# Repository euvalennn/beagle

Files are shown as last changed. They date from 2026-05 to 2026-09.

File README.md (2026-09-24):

# beagle

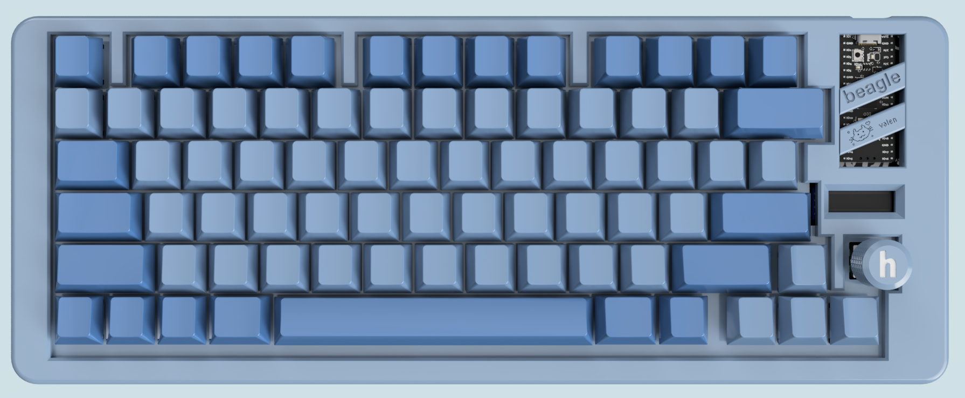
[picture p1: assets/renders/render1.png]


my first (and only) keyboard!!

It's been almost a month since I started working on this! I wanted to try making a keyboard myself, but soon realized it's easier said than done 😭\
Overall I'm really happy with how it turned out, I have to admit it took me a pretty long time to finish but I wanted to make sure it was polished and I think I've achieved that :)

The layout resembles that of my MacBook's keyboard (since that's what I mostly use) and I also included a rotary encoder (intended for volume but can be customized) and an OLED screen to show animations, graphics, or anything else you may want to put there. There's an SK6812MINI-E behind every switch to allow for individual key backlighting.\
I designed the case in Fusion and it consists of an angled base for the keyboard to sit on, the main body of the case covering all of the components from the sides, a plate, and a top part covering it. All of the parts will be put together with 20mm M3 screws, one in every corner.\
The PCB also features a silkscreen hand-drawn by myself! :D

## Features:

- 77 total keys
- rp2040 based mcu
- customizable knob to control whatever your heart desires
- 0.91" OLED screen for graphics and useful info
- neopixels under each switch for RGB backlighting
- sick hand-drawn silkscreen!!

## IRL build pictures

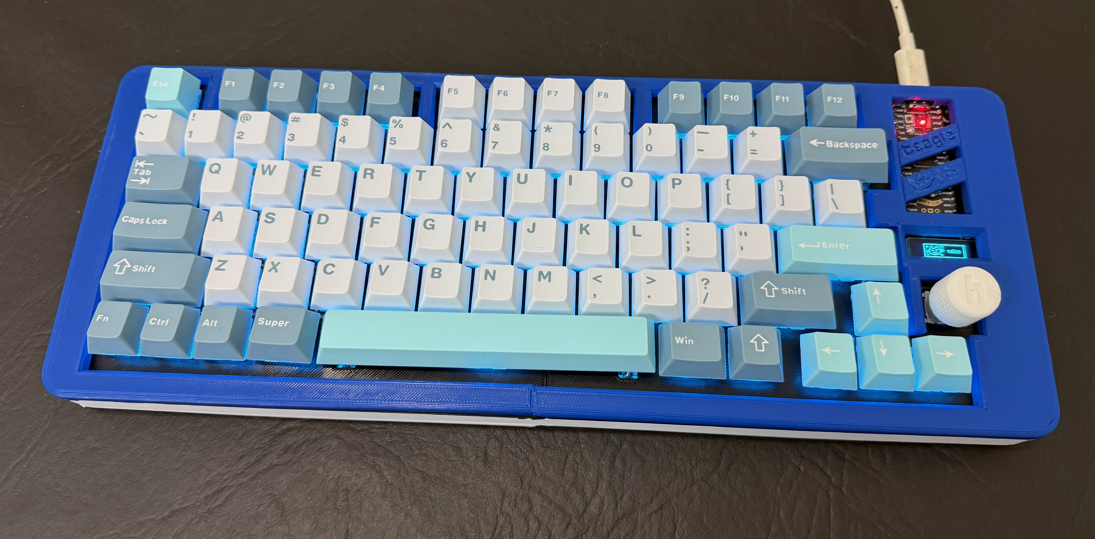
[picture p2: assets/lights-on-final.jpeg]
\
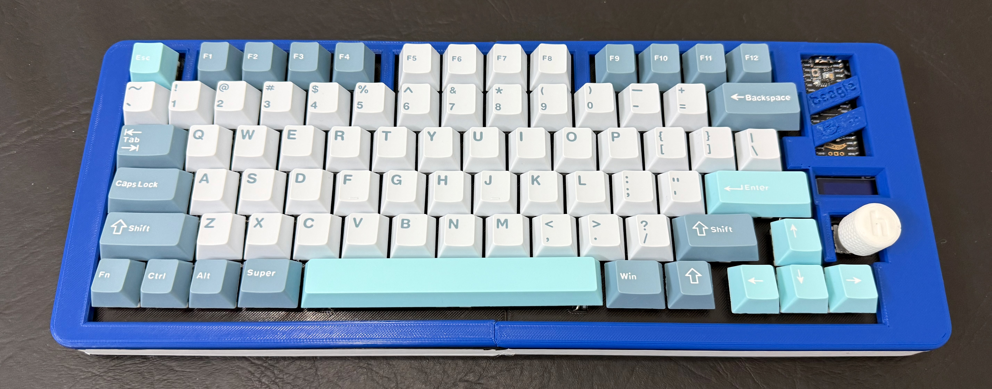
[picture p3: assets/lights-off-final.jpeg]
\
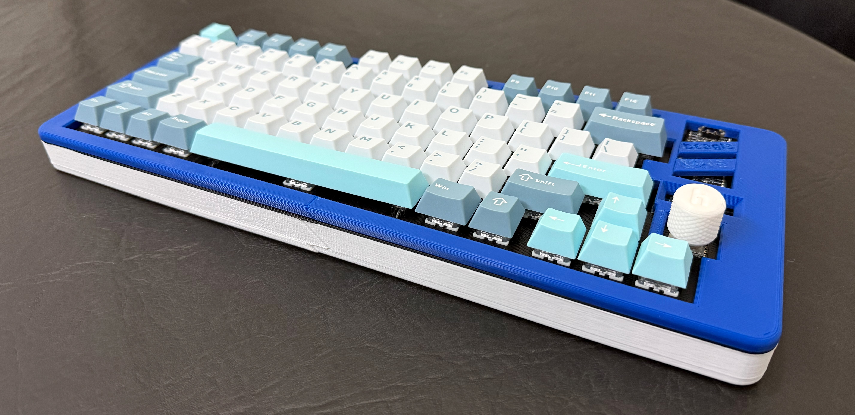
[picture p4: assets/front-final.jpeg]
\
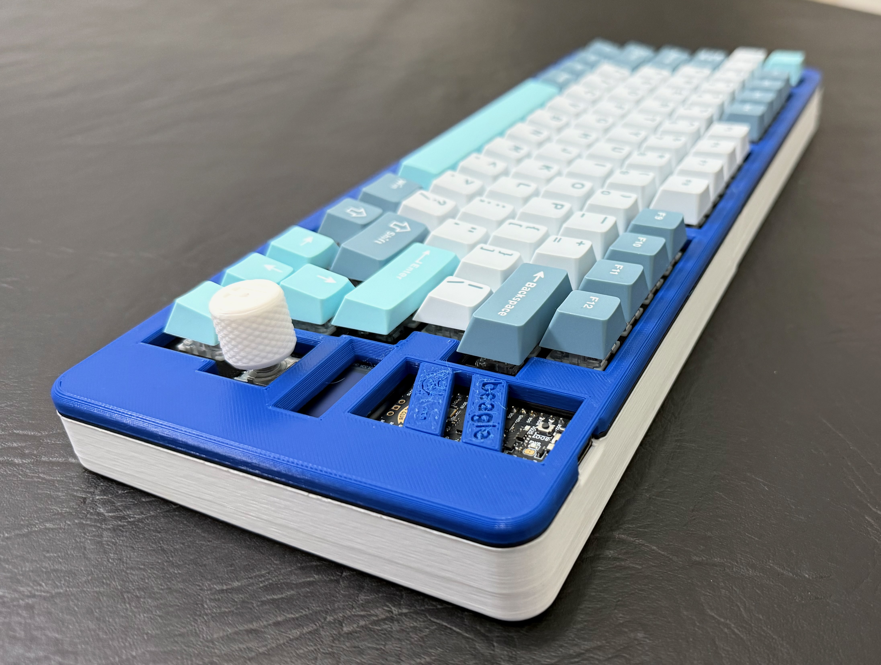
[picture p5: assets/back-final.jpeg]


## More CAD pictures

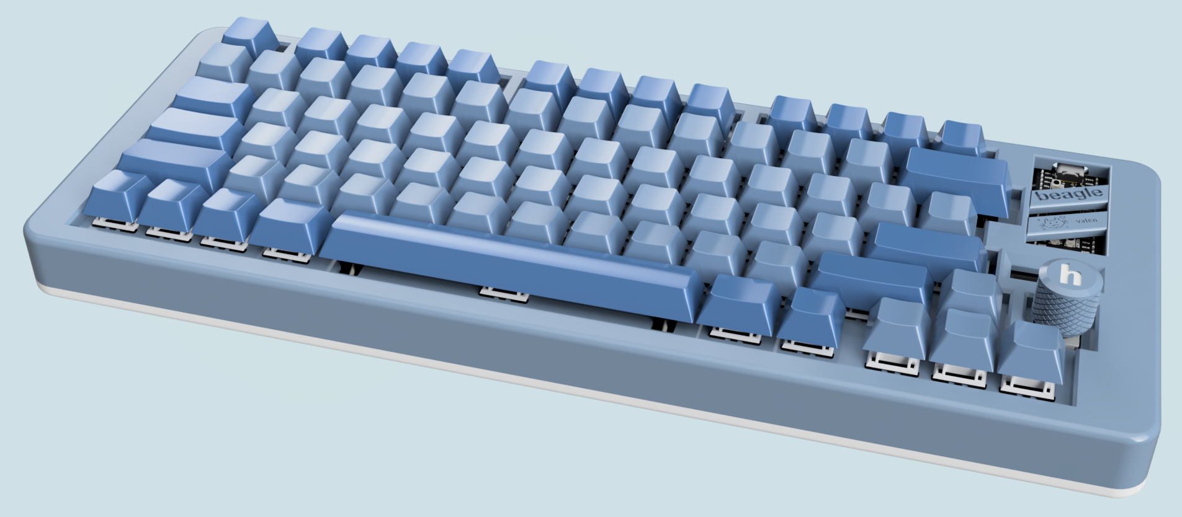
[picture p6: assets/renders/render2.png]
\
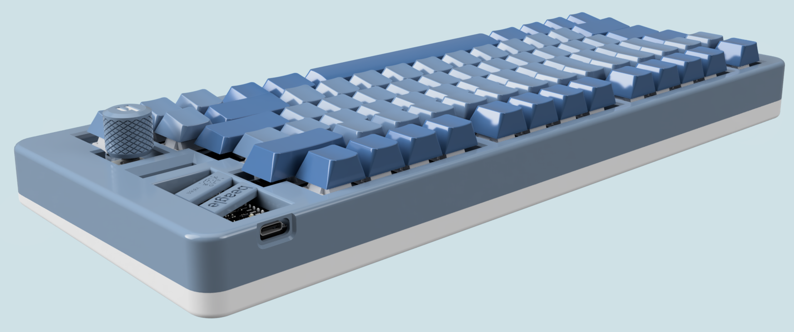
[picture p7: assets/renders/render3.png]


NOTE: the actual color scheme is subject to change based on availability 😭

## PCB and schematics screenshots

see it online [here](https://kicanvas.org/?repo=https%3A%2F%2Fgithub.com%2Feuvalennn%2Fbeagle%2Ftree%2Fmain%2Fpcb)!

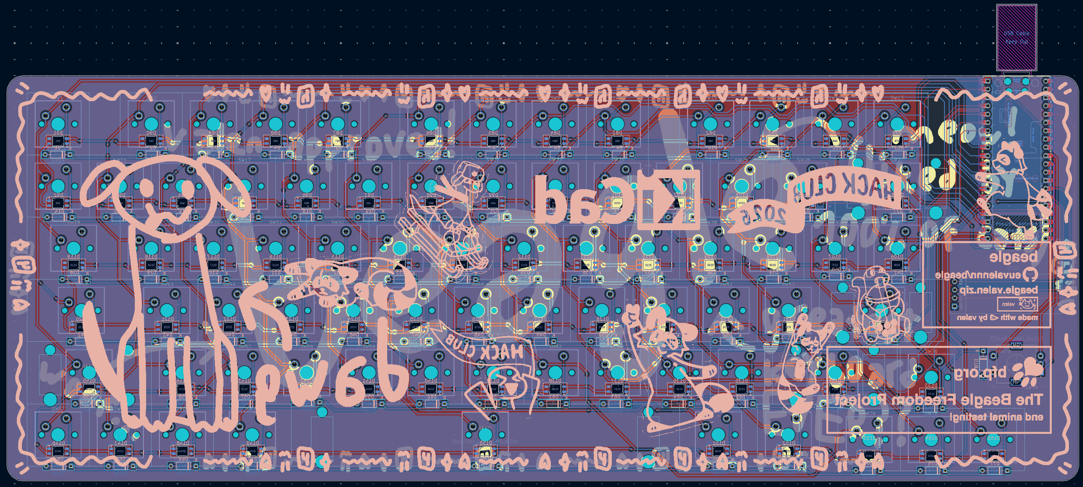
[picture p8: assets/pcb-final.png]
\
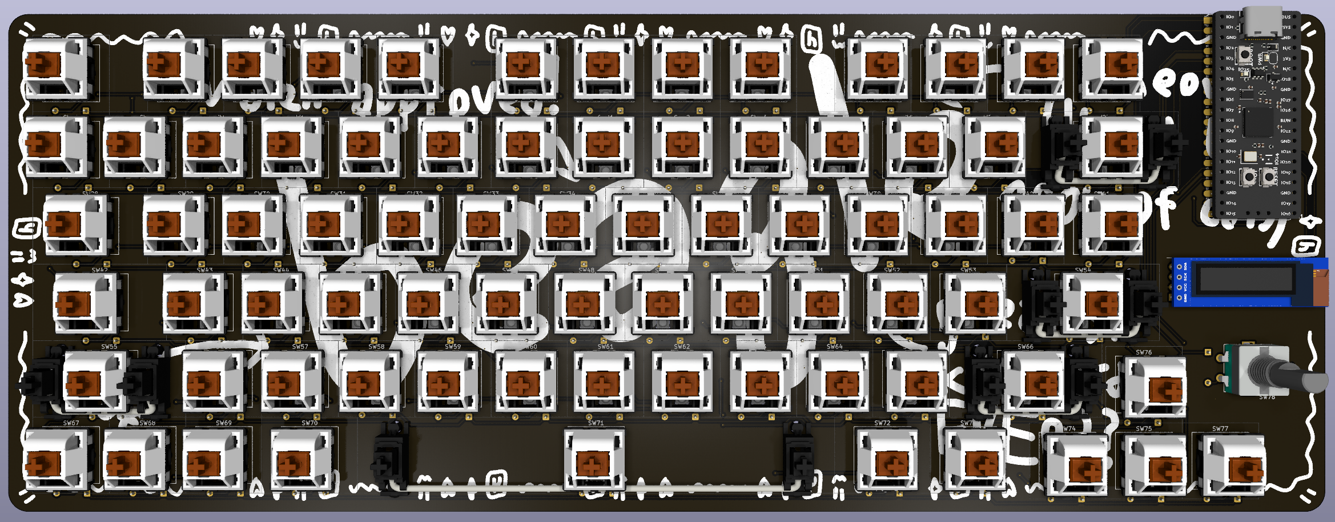
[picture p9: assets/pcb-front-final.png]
\
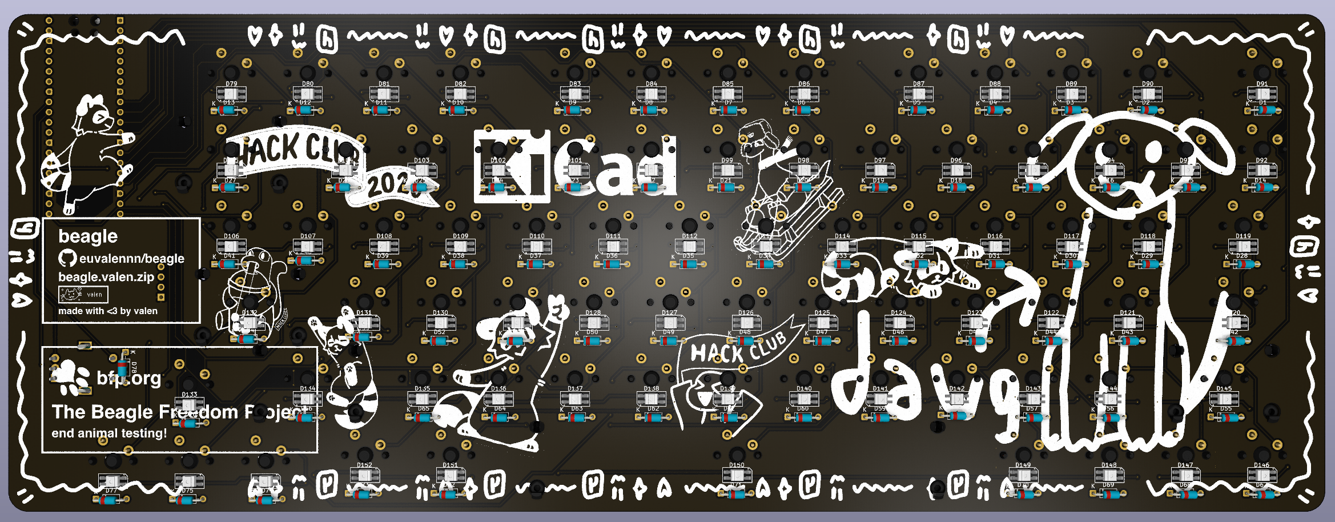
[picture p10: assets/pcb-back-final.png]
\
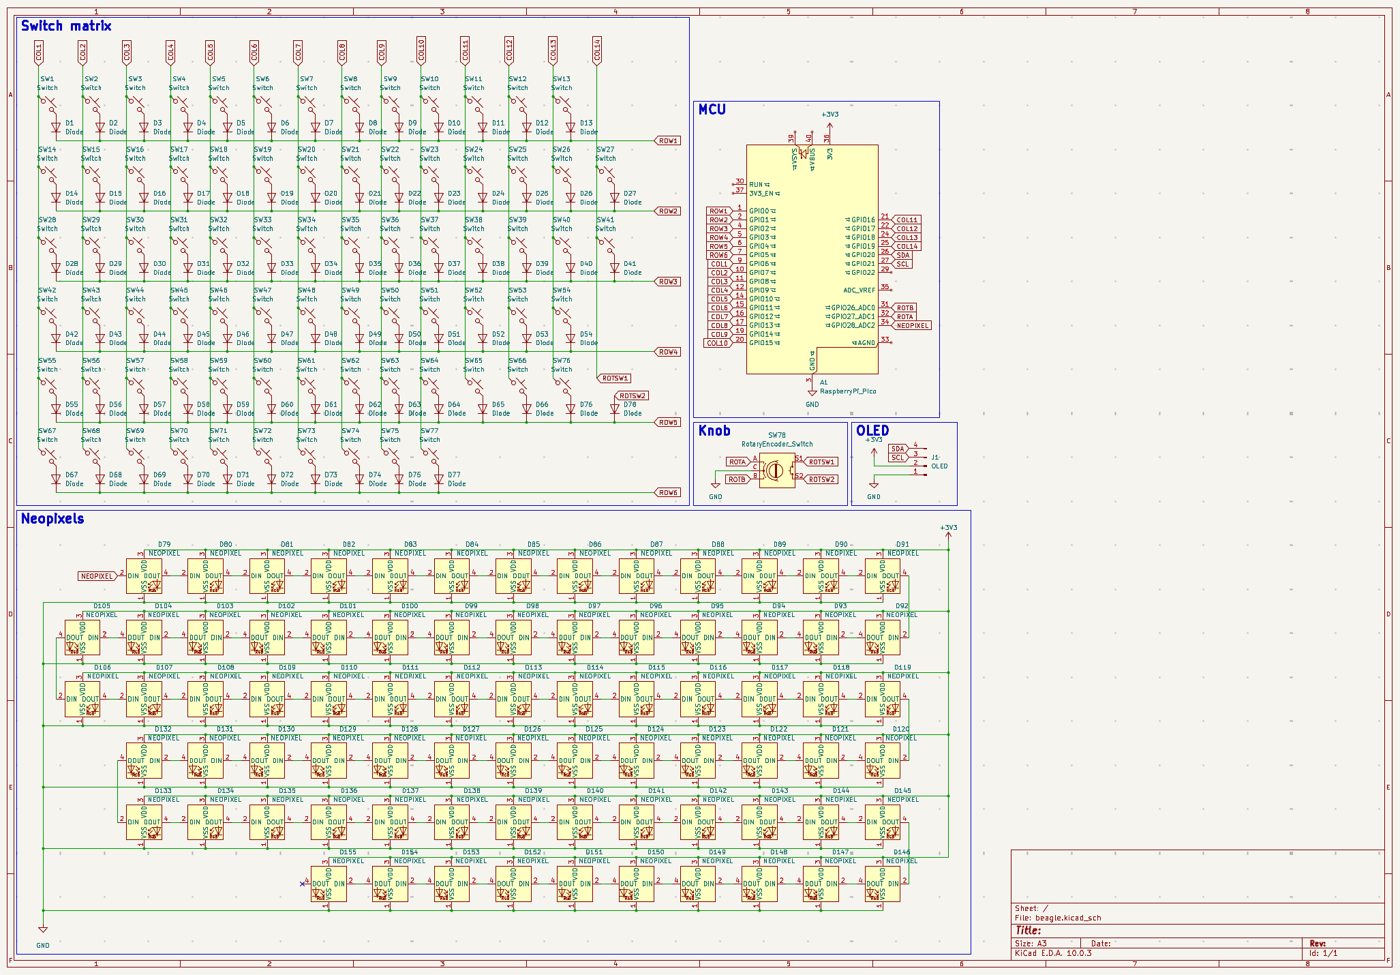
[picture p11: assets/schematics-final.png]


## BOM

| Item | Quantity | Price | Total  | URL |
| --- | --- | --- | --- | --- |
| Orpheus Pico | 1 | Already owned | $0 | N/A |
| OLED display | 1 | $6.06 | $6.06  | https://es.aliexpress.com/item/1005008640108394.html |
| EC11 Rotary encoder | 1 | $5.33 | $5.33  | https://es.aliexpress.com/item/1005007644083514.html |
| SK6812MINI-E | 100 | $10.53 | $10.53 | https://es.aliexpress.com/item/1005005193716172.html |
| 1N4148 diodes | 100 | $5.26 | $5.26  | https://es.aliexpress.com/item/4001126137167.html |
| Keyboard switches | 80 | $1.75 | $1.75  | https://es.aliexpress.com/item/1005012157731141.html |
| M3x5x4 heatset inserts | 30 | $7.04 | $7.04  | https://es.aliexpress.com/item/1005006071488810.html |
| M3 20mm screws | 50 | $8.14 | $8.14  | https://es.aliexpress.com/item/32810872544.html |
| Stabilizers set | 1 | $9.97 | $9.97  | https://es.aliexpress.com/item/1005004229140548.html |
| Keycap set | 1 | $15.51 | $15.51 | https://es.aliexpress.com/item/1005007321700850.html |
| AliExpress VAT | 1 | Included in item prices | $0 | N/A |
| PCB | 1 | $22.20 | $22.40 | https://jlcpcb.com |
| PCB shipping | 1 | $48.19 | $47.36 | https://jlcpcb.com |
| 3D printed case | 1 | Will get someone to print it for me | $0 | N/A |
| 3D printed plate | 1 | Will get someone to print it for me | $0 | N/A |
| | | | | |
| Total cost: | $139.35  | | | |

---

thank you to [hack club](https://hackclub.com) for funding this project :D

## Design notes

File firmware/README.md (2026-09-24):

This QMK firmware sets all of the neopixels to a blue-ish color, makes the rotary encoder control the volume and displays my 88x31 button on the OLED display. The layout is the same as that of a regular US MacBook keyboard, including the globe/fn key in the bottom-left corner to switch keyboard layouts or open the emoji picker on macOS.

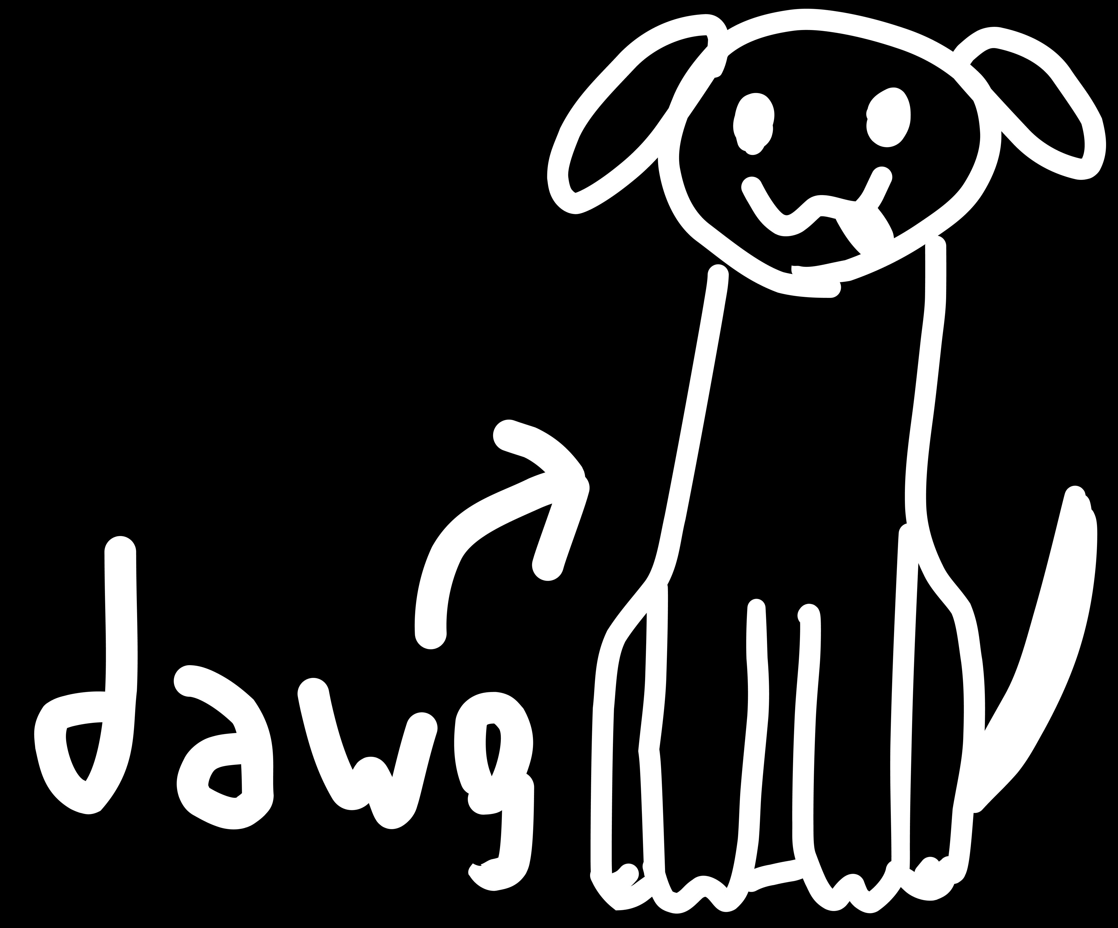
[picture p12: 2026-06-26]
pcb/assets/dawg.png

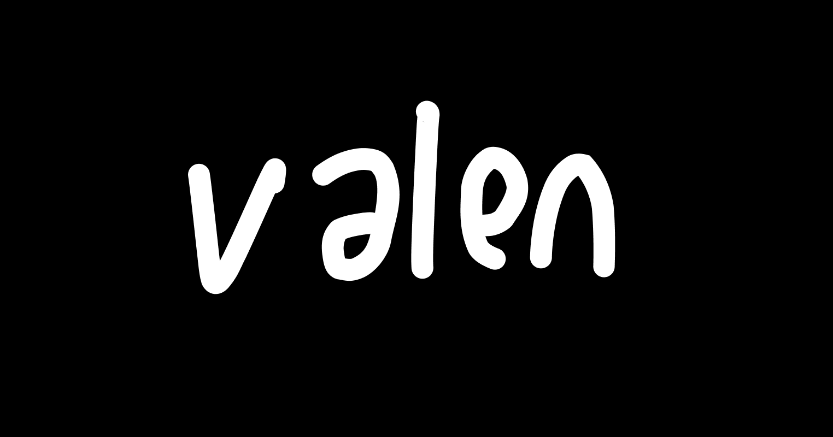
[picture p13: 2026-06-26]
pcb/assets/valen.png

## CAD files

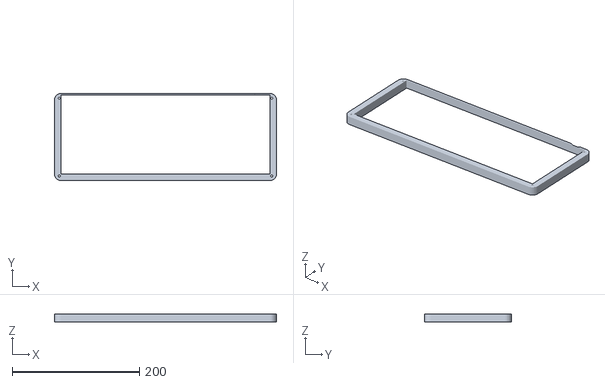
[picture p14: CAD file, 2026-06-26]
production/main-body.stl
349.0 x 137.1 x 13.0

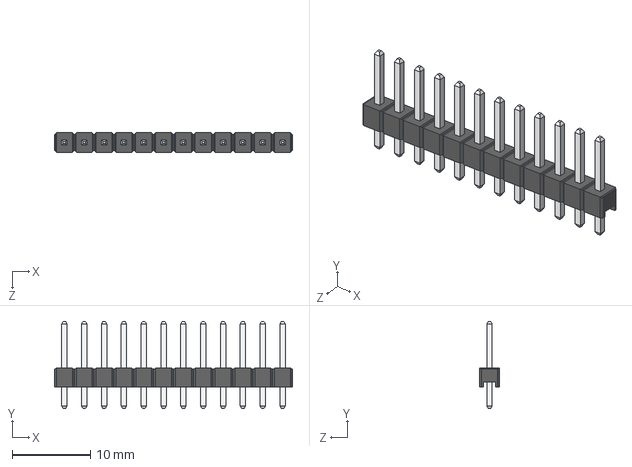
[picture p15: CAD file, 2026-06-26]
pcb/assets/3dmodels/2-54mm-male-pin-header/Step/100mill Male Pin Header_12P_Bk.STEP
30.5 x 11.2 x 2.50 mm

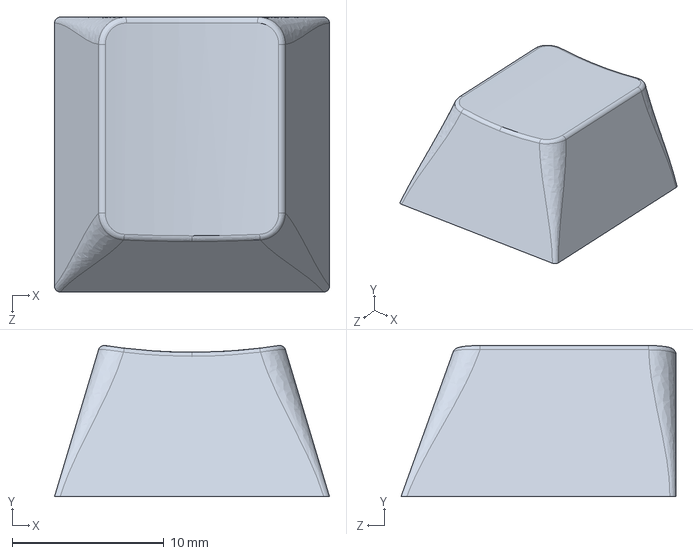
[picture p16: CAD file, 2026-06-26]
pcb/assets/3dmodels/cherry_mx_keycaps/r1/r1_100.STEP
18.1 x 9.95 x 18.1 mm

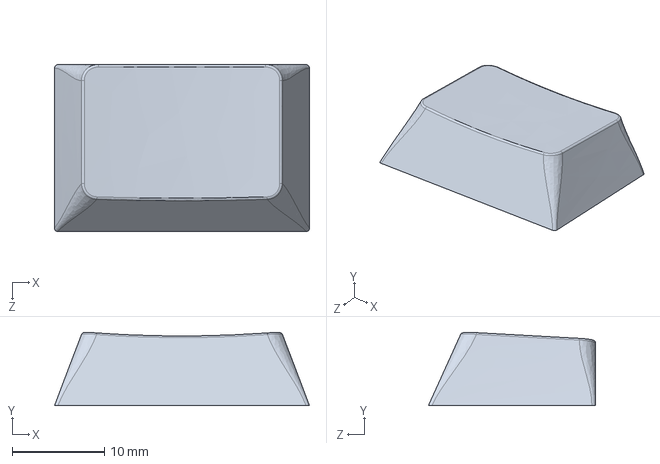
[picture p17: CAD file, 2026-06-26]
pcb/assets/3dmodels/cherry_mx_keycaps/r2/r2_150.STEP
27.6 x 7.92 x 18.1 mm

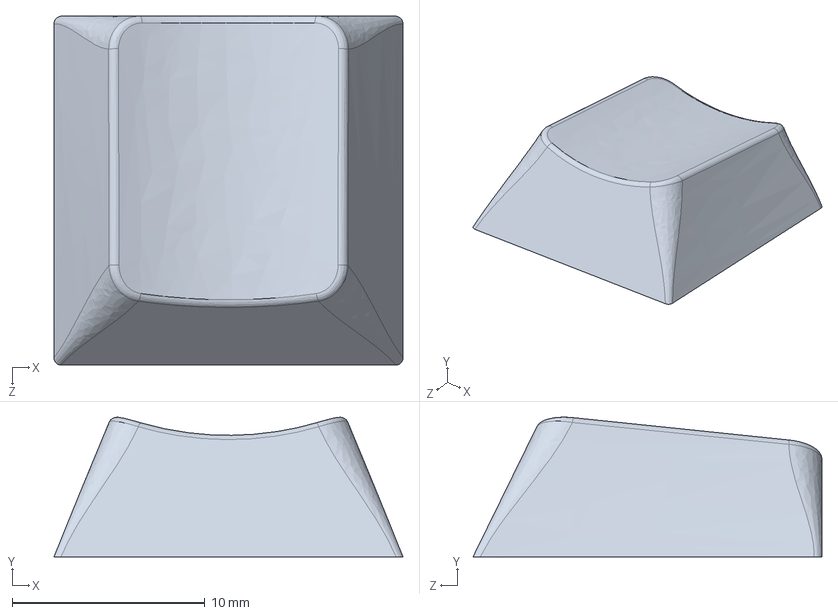
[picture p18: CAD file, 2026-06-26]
pcb/assets/3dmodels/cherry_mx_keycaps/r3/r3_100_sculpted.STEP
18.1 x 7.24 x 18.1 mm

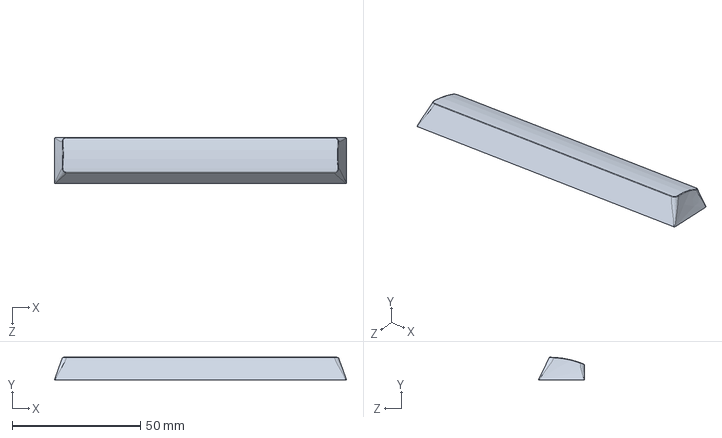
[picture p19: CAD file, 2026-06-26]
pcb/assets/3dmodels/cherry_mx_keycaps/r4/r4_600.STEP
114.0 x 8.80 x 18.0 mm

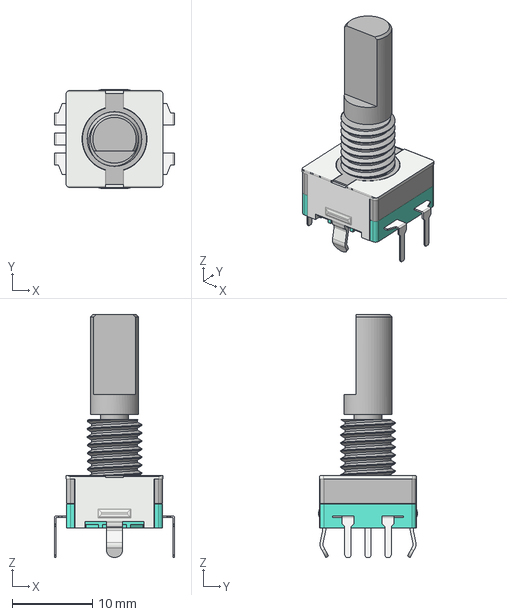
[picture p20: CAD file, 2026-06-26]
pcb/assets/3dmodels/EC11_NEW.STEP
15.0 x 12.3 x 30.3 mm

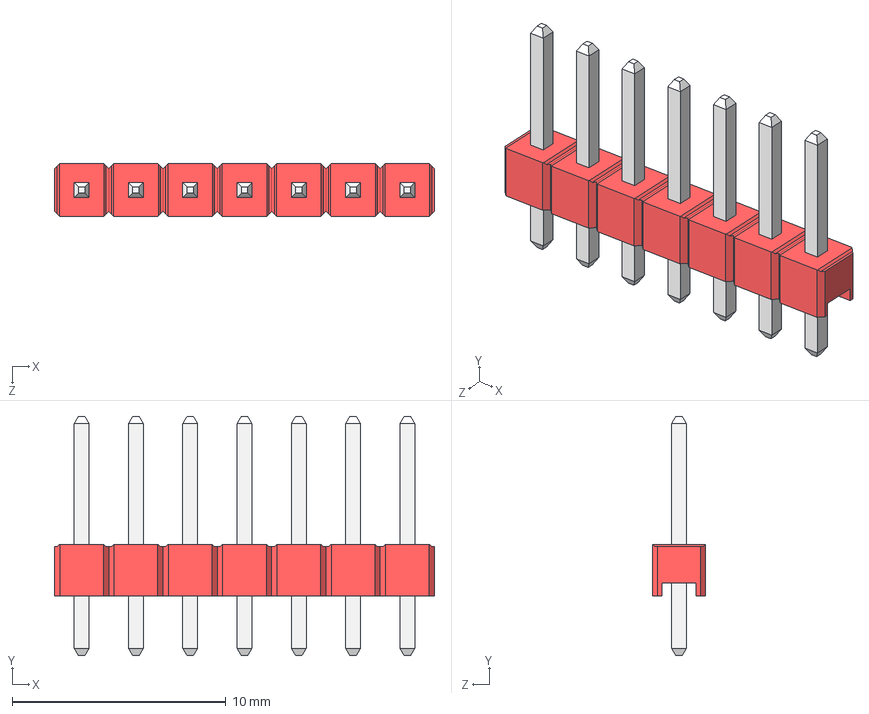
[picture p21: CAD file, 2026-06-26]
pcb/assets/3dmodels/2-54mm-male-pin-header/Step/100mill Male Pin Header_7P_R.STEP
17.8 x 11.2 x 2.50 mm

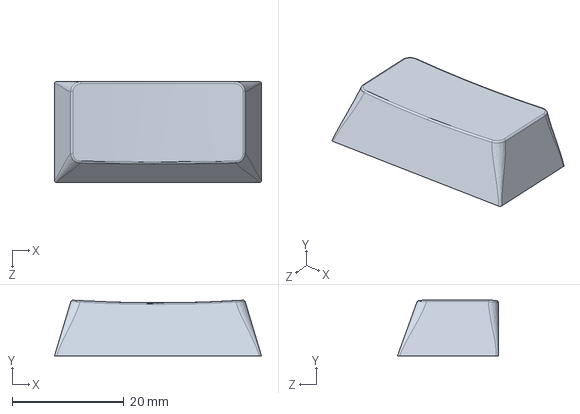
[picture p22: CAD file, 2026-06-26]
pcb/assets/3dmodels/cherry_mx_keycaps/r1/r1_200.STEP
37.1 x 9.98 x 18.1 mm

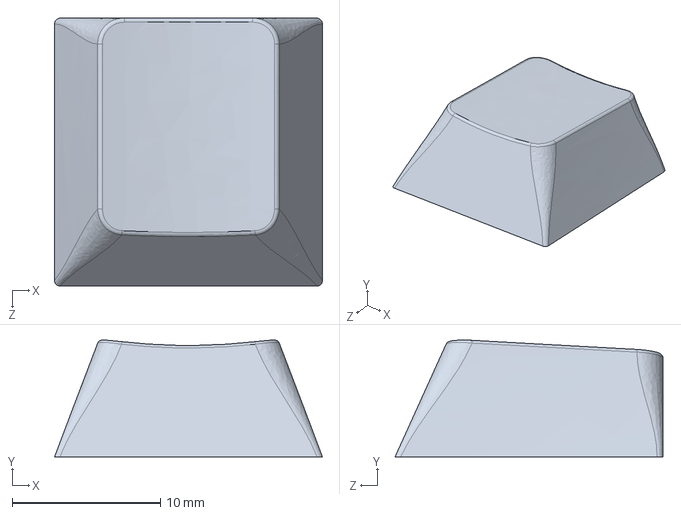
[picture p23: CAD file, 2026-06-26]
pcb/assets/3dmodels/cherry_mx_keycaps/r2/r2_100.STEP
18.1 x 7.89 x 18.1 mm

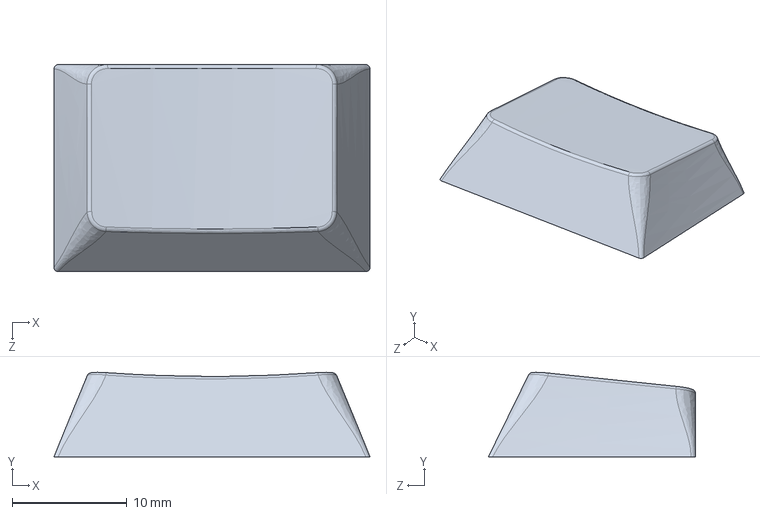
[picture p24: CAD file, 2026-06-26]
pcb/assets/3dmodels/cherry_mx_keycaps/r3/r3_150.STEP
27.6 x 7.38 x 18.1 mm

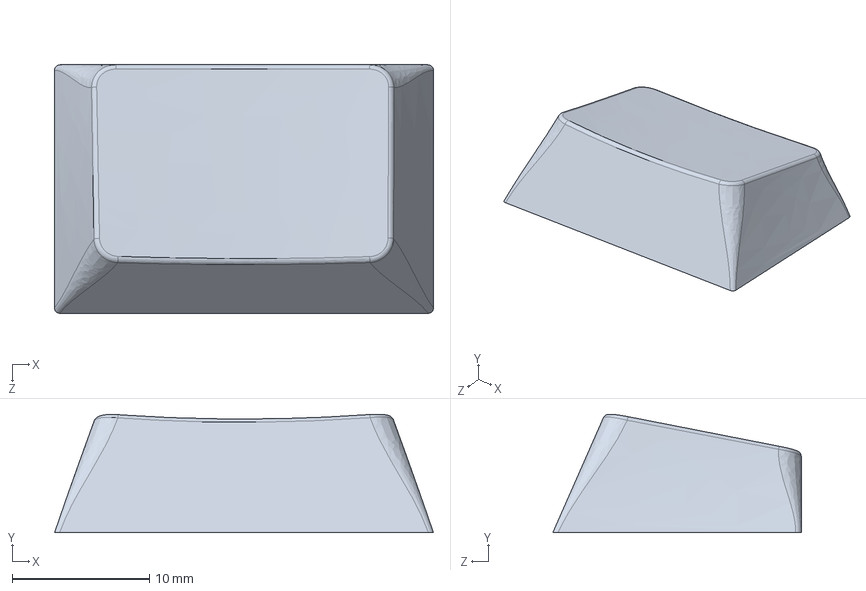
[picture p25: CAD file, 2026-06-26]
pcb/assets/3dmodels/cherry_mx_keycaps/r4/r4_150.STEP
27.6 x 8.63 x 18.1 mm

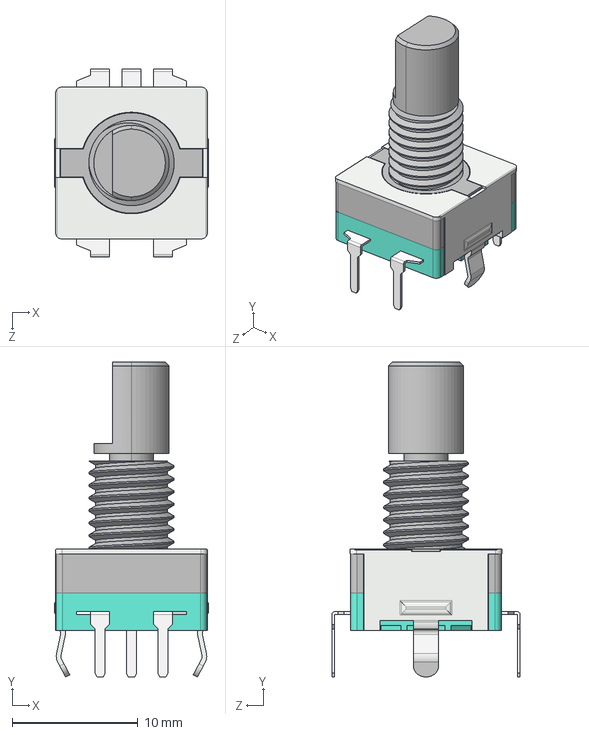
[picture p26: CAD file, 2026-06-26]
pcb/assets/3dmodels/EC11.STEP
12.3 x 25.1 x 15.0 mm

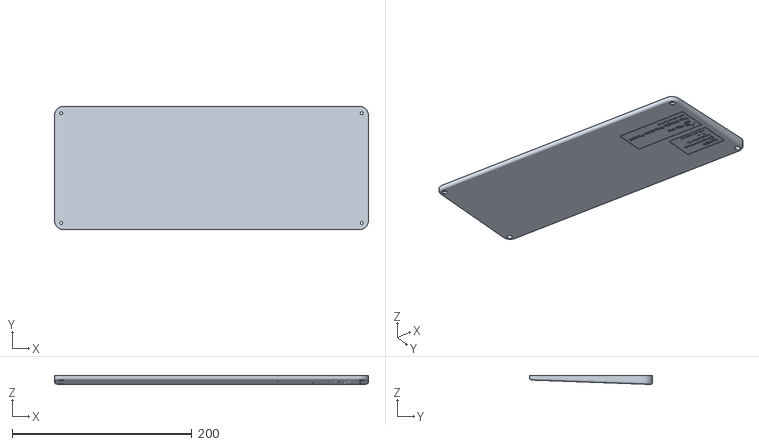
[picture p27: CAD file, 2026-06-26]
production/base.stl
349.0 x 137.0 x 9.91

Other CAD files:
pcb/assets/3dmodels/0.91in OLED Module - Without Glass.stp
pcb/assets/3dmodels/2-54mm-male-pin-header/Step/100mill Male Pin Header_8P_Bk.STEP
pcb/assets/3dmodels/cherry_mx_keycaps/r3/r3_100_bar.STEP
pcb/assets/3dmodels/cherry_mx_keycaps/r4/r3-4_200vert.STEP
pcb/assets/3dmodels/2-54mm-male-pin-header/Step/100mill Male Pin Header_10P_Bk.STEP
pcb/assets/3dmodels/2-54mm-male-pin-header/Step/100mill Male Pin Header_10P_R.STEP
pcb/assets/3dmodels/2-54mm-male-pin-header/Step/100mill Male Pin Header_10P_Y.STEP
pcb/assets/3dmodels/2-54mm-male-pin-header/Step/100mill Male Pin Header_12P_R.STEP
pcb/assets/3dmodels/2-54mm-male-pin-header/Step/100mill Male Pin Header_12P_Y.STEP
pcb/assets/3dmodels/2-54mm-male-pin-header/Step/100mill Male Pin Header_15P_Bk.STEP
pcb/assets/3dmodels/2-54mm-male-pin-header/Step/100mill Male Pin Header_15P_R.STEP
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

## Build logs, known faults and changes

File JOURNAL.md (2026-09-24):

# May 26: Did research, started (and finished!) first schematic design, and positioned all components in the PCB

I wasn't really sure if I could make this because it's been a really long time since I last made a hardware project and making a keyboard sounds a bit complicated but I finally decided to give it a try, so here we are :D

I'm planning on making a 75% keyboard with a 0.91" OLED display, a rotary encoder for volume and an Orpheus Pico as the MCU. It's my first time making a keyboard and I'm not too sure how hard it will be but I've been doing some research and already started designing the PCB.

Here's how the schematic is looking so far:

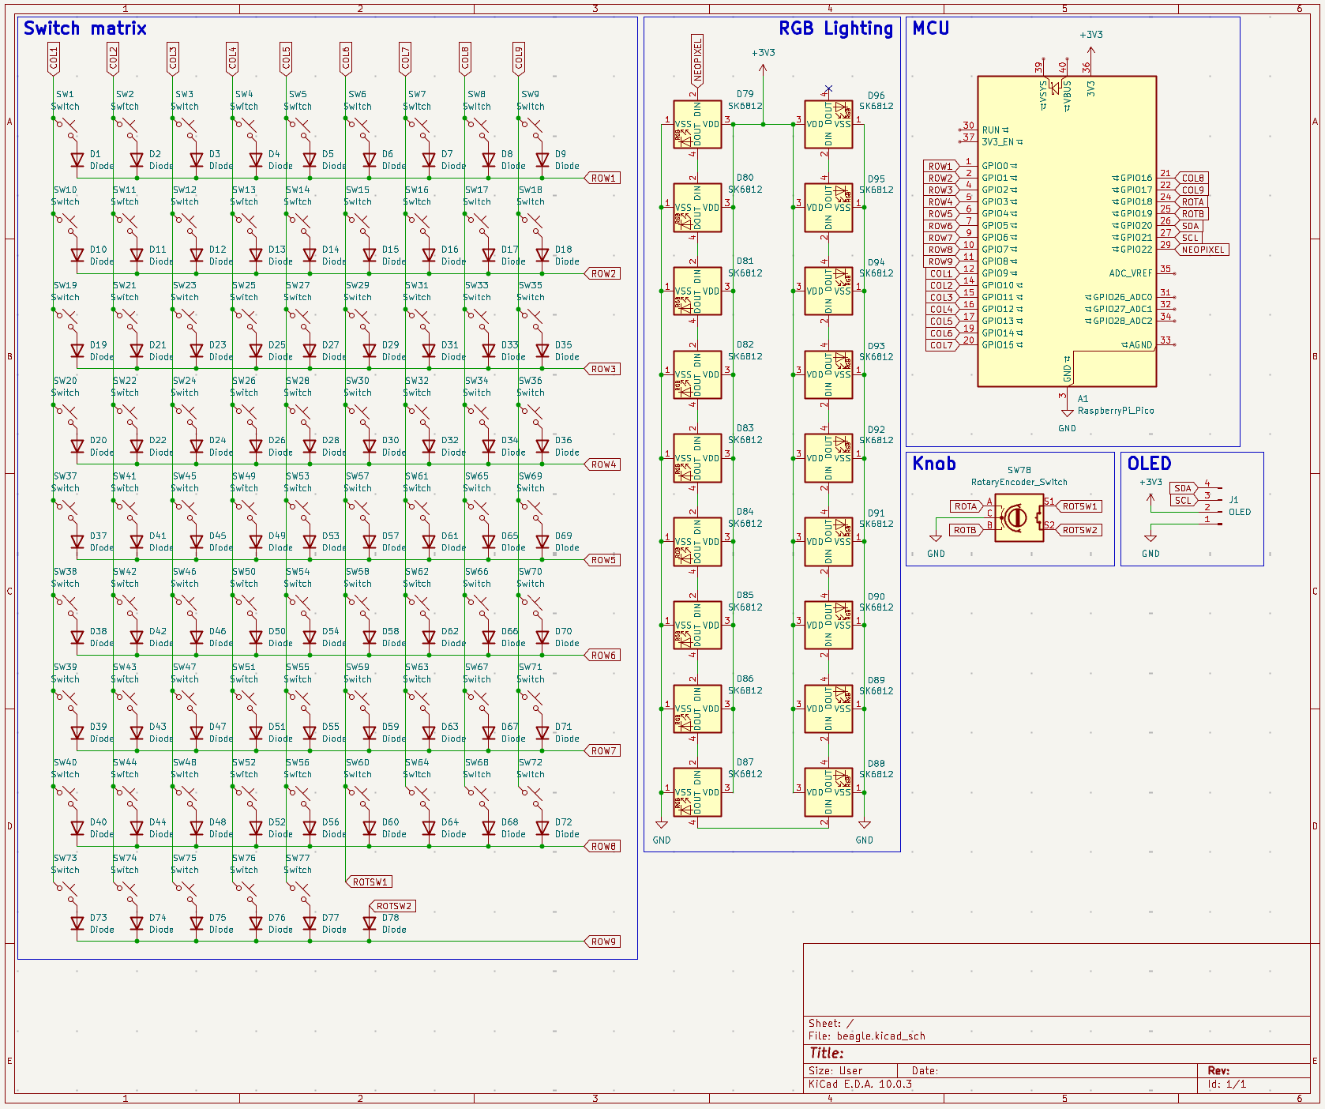
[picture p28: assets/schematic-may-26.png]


I positioned all components in the PCB, although I had to spend some time looking for 3D models and footprints for every one of them (especially the stabilizers) and seeing where to place everything (I'm still not sure if I'll keep the current layout but it serves as a starting point for now, I already spent way too much time on this today so I'll figure it out later 😭)

Here's how the PCB looks right now, both from the editor and 3D viewer:

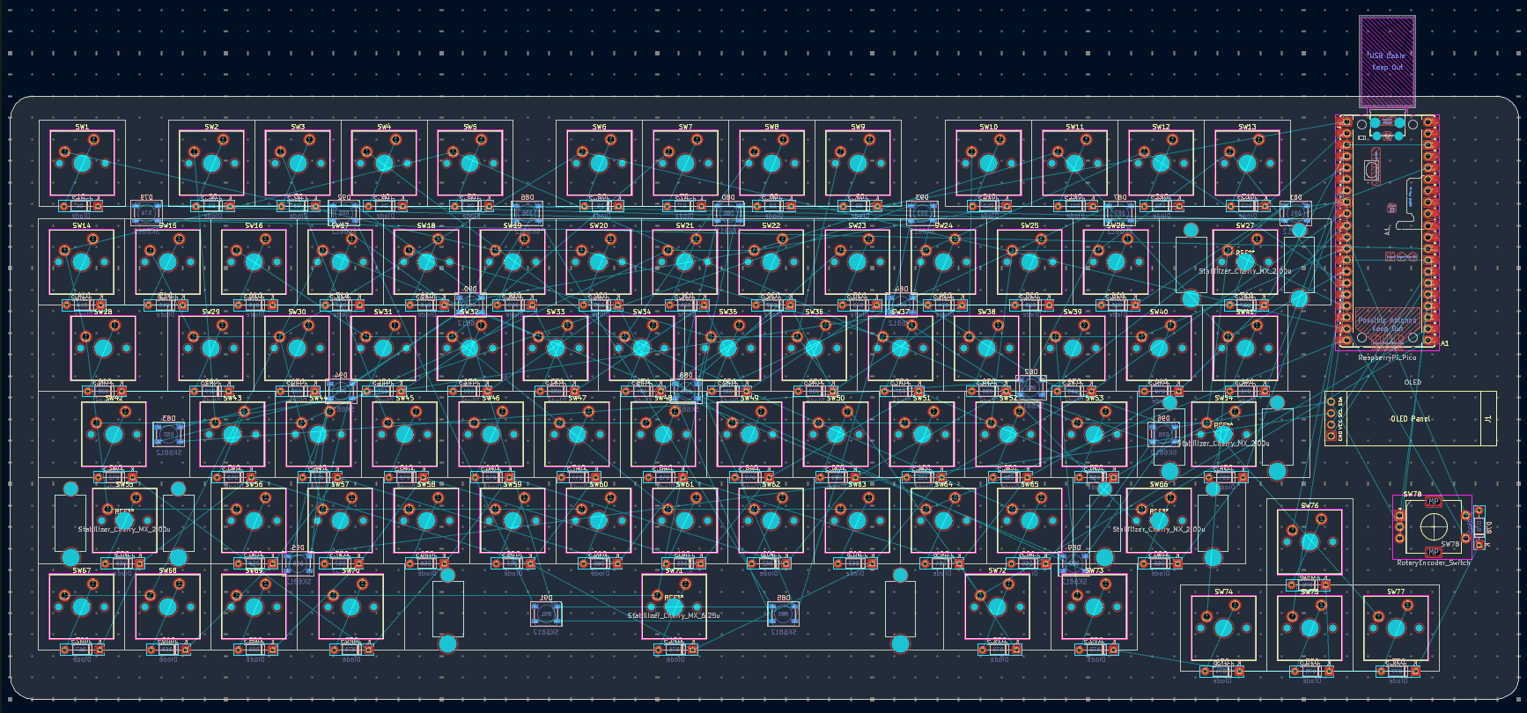
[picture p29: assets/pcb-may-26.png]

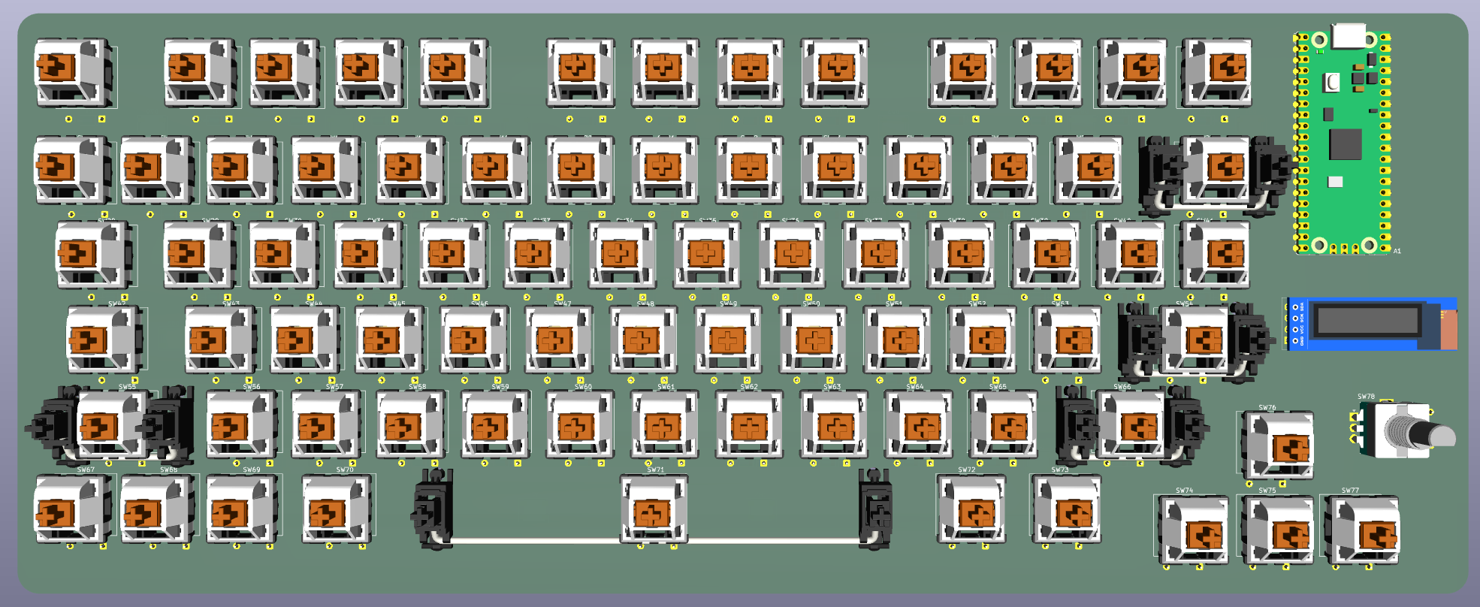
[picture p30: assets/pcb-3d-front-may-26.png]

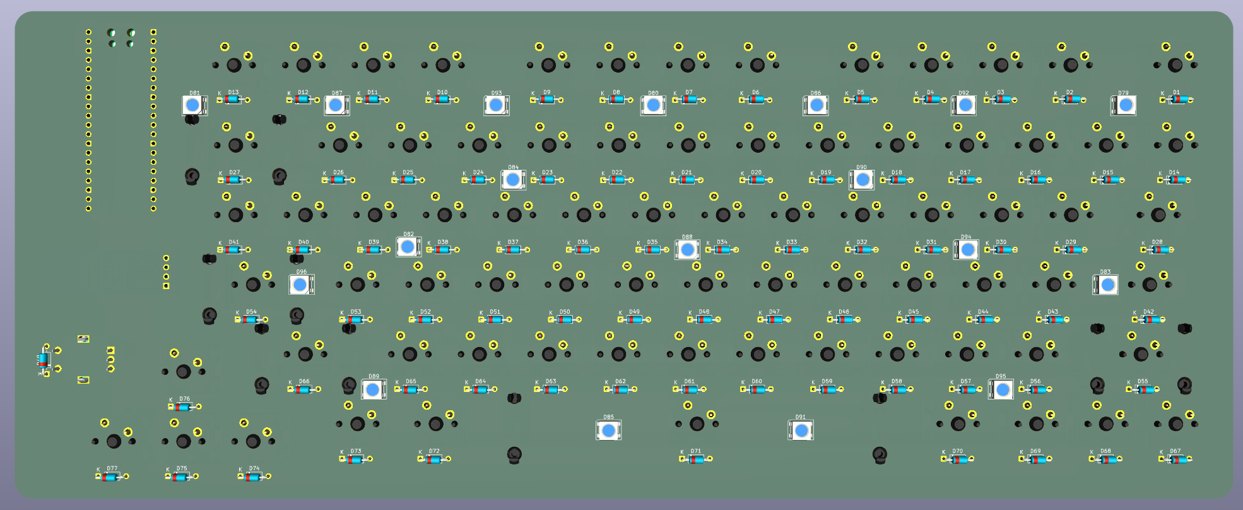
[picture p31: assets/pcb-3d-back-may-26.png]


For the next time I work on this I'd like to figure out the final layout and start routing the PCB!

**Time spent this session: 4h**

# May 28: Updated PCB and switch matrix (schematic) and started routing

I got a lot of stuff done today!!

First off, I moved around some components and switches in the PCB so that the spacing makes more sense and I can make the PCB smaller.

Once I was happy with how the general layout looked, I was going to start routing the switches but then I realized the rows and columns were a total mess :pf:

I had to change the switch matrix in the schematic to reflect how the switches were actually laid out in the PCB and therefore make routing easier.

Here's how the matrix looks now:

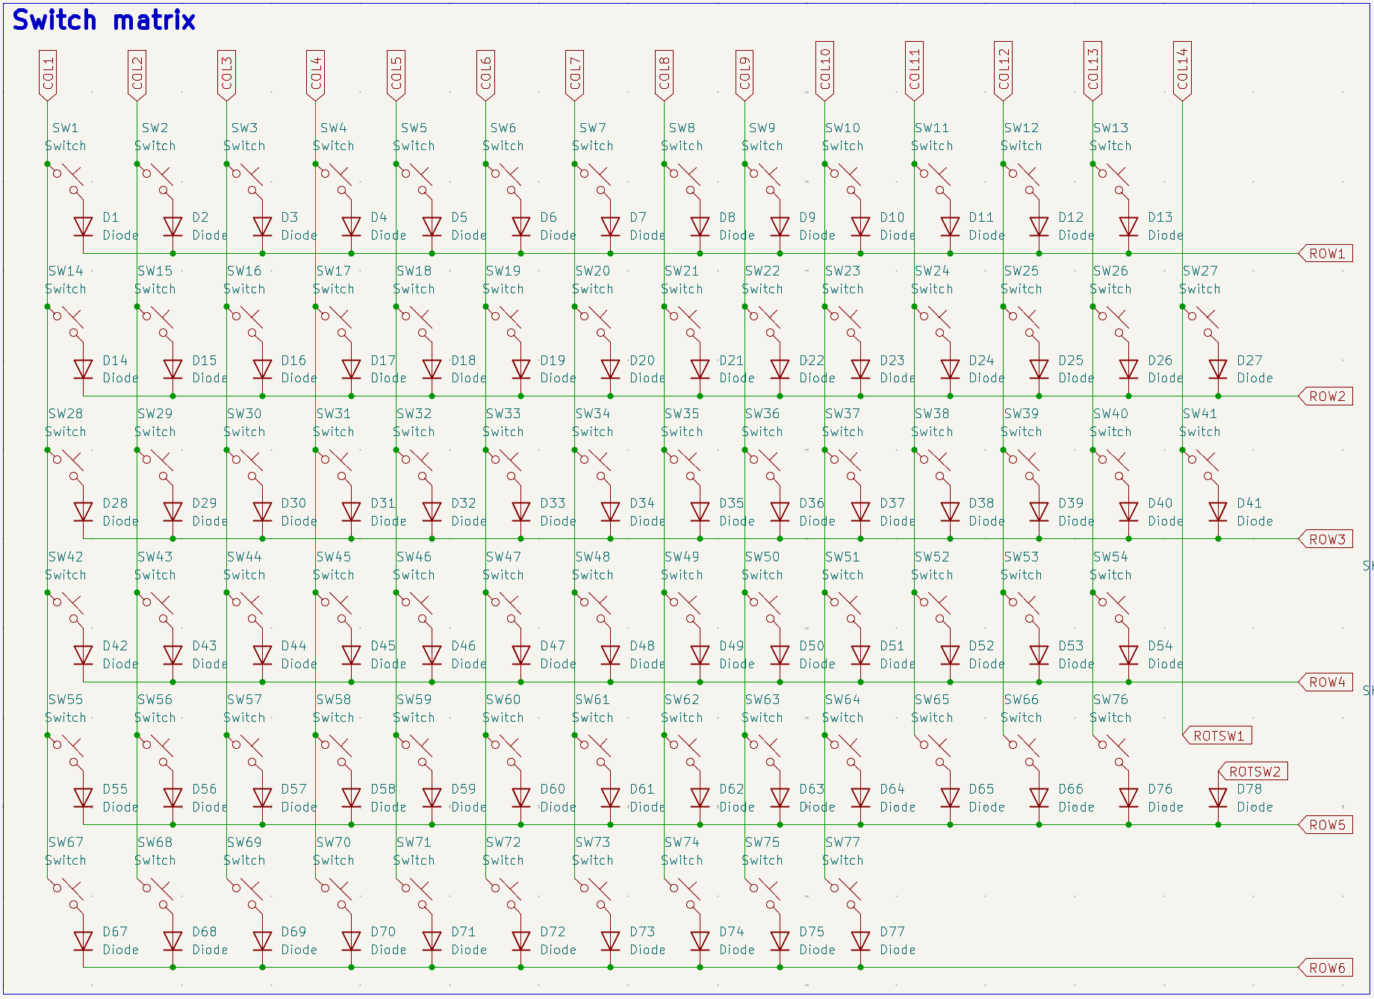
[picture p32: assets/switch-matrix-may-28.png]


Once that was done I started routing everything! I had to redo it a couple of times but here's how the traces look now (I think it looks pretty neat!)

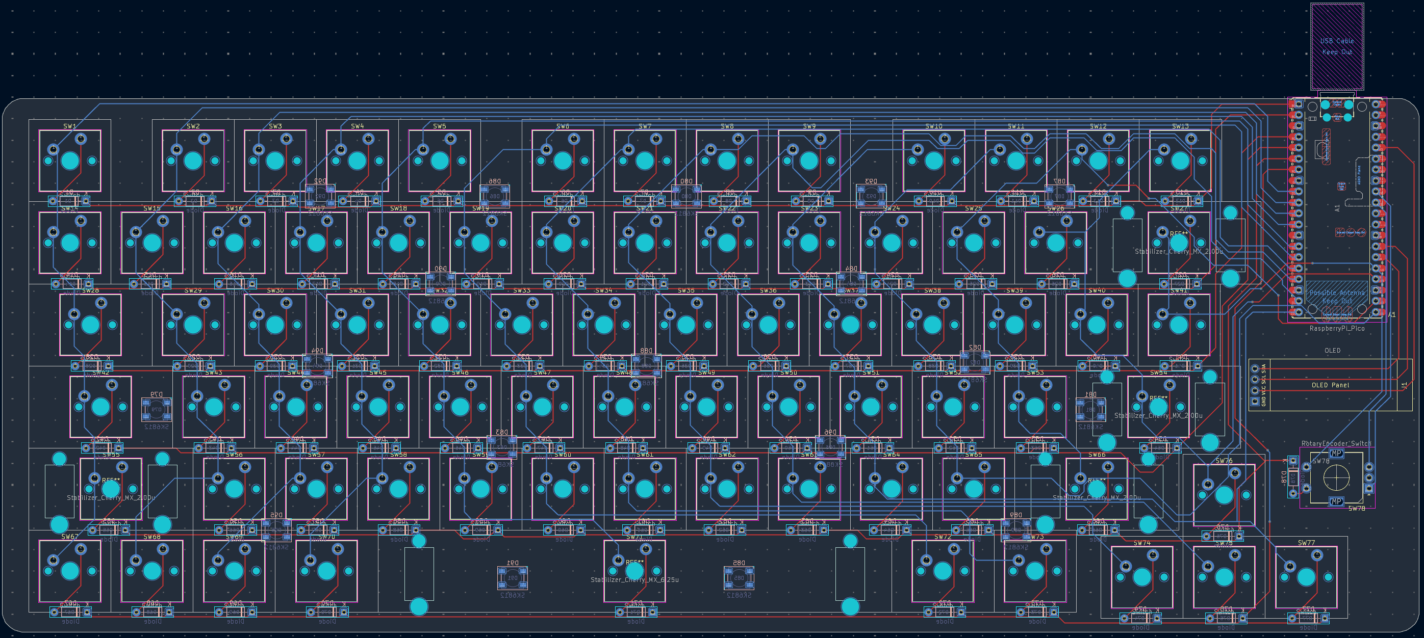
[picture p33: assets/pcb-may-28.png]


Now I only have to route the neopixels (I'll also have to update the schematic for those so that the connections make sense) and add silkscreen art. Once I'm done with that I think I can move on to the case design :D

Here's how the PCB looks right now from the 3D view:

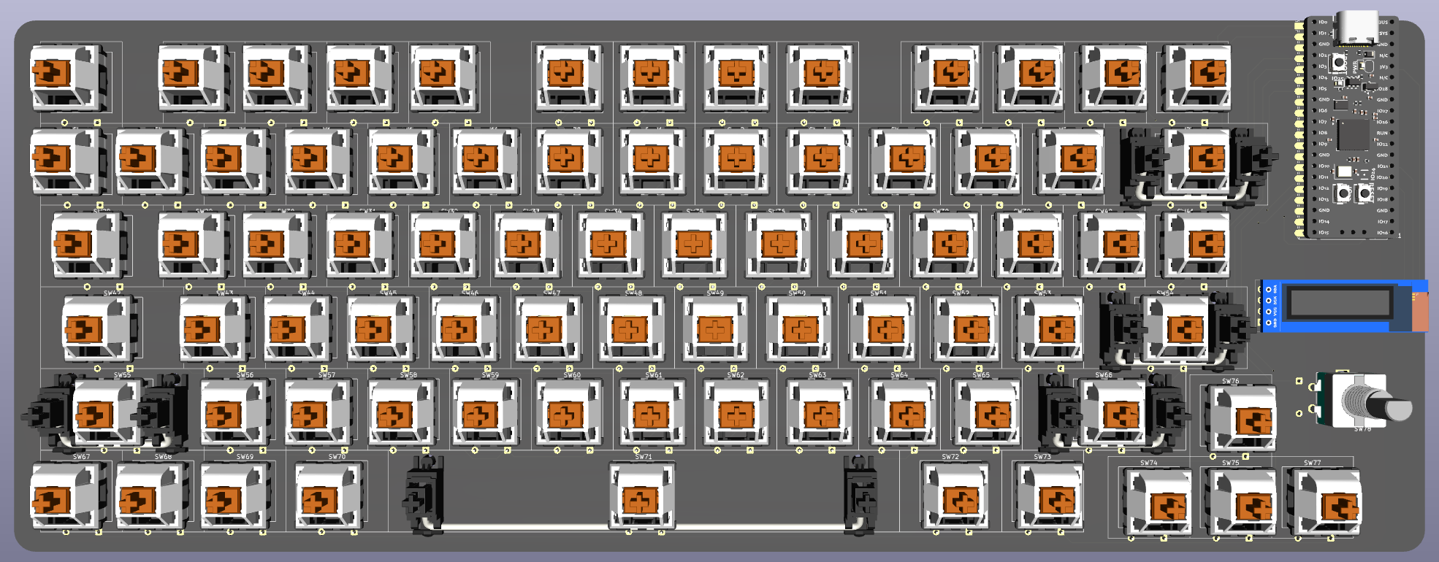
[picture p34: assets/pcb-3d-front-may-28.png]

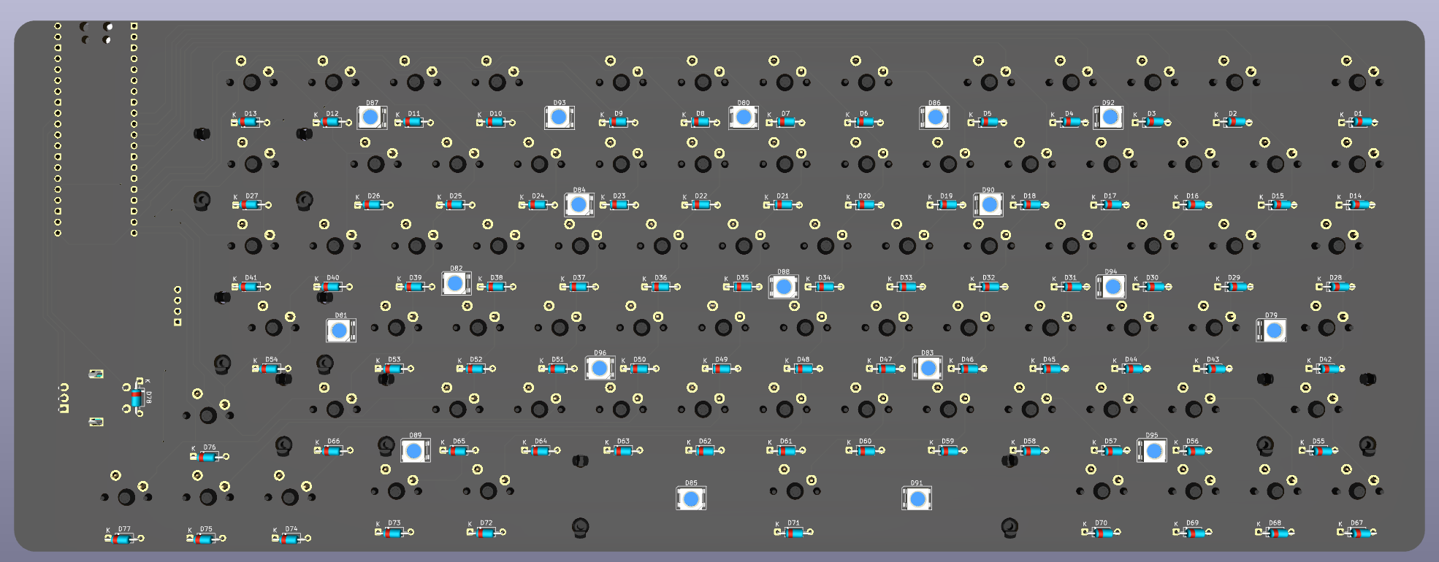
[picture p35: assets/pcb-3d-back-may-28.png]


**Time spent this session: 4h**

# May 30: Did more routing and fixed DRC errors

Today I changed the neopixels' connections on the schematic so that they match the actual layout on the PCB and then started routing! I actually finished routing all of them as well as the VCC connections, so the only thing left to route now is GND. I also ran a DRC check and moved around some components that were overlapping so I shouldn't have any problems with that now.
Here's a pic of the PCB right now:

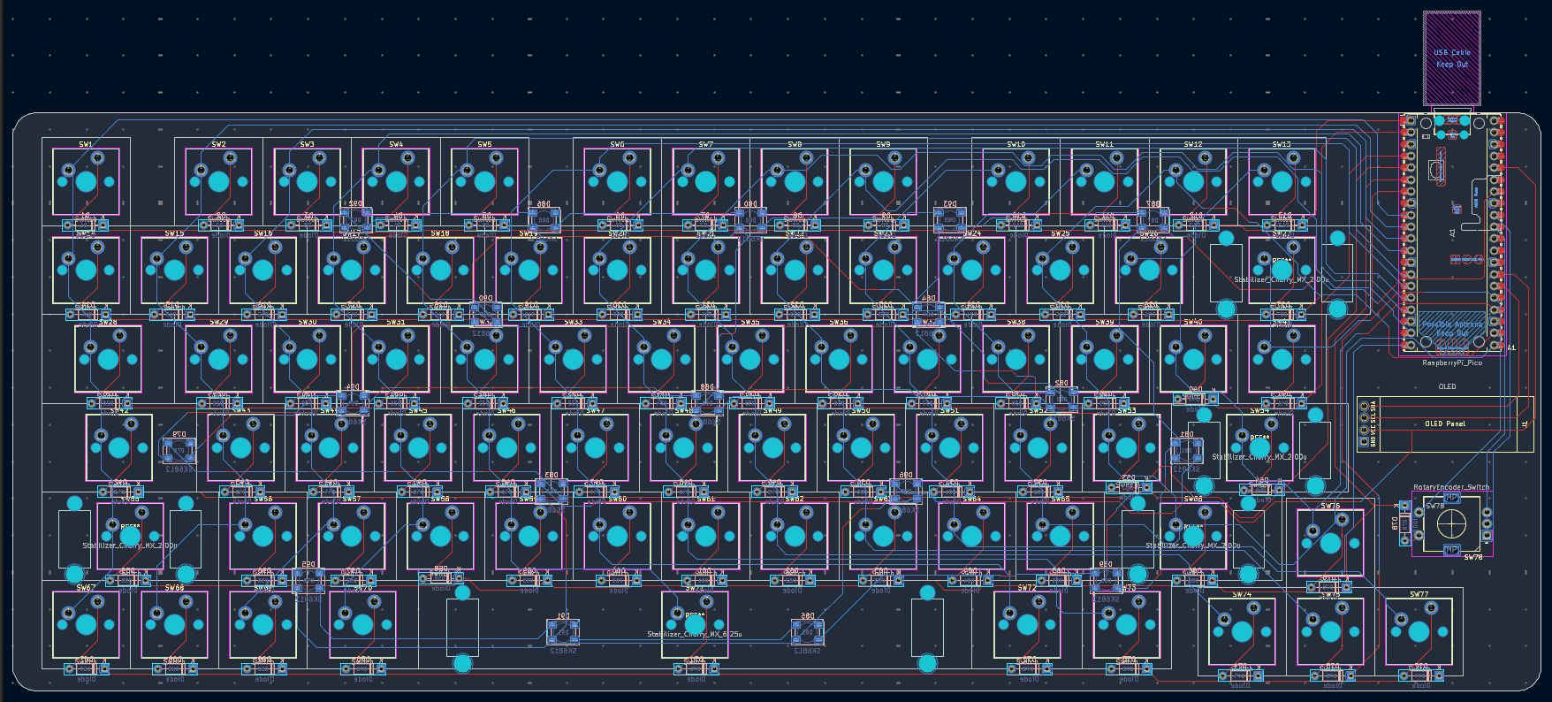
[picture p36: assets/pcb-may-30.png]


Even though I already finished routing all the neopixels, I think I might get rid of them and replace them with reverse mount ones on every switch. Right now I don't think they'll be too visible as the case will (probably) be 3D printed and all the neopixels are on the back on the PCB :pf:

Anyway once I figure the neopixels thing out I want to start with the case design!!

Wish me luck 😭

**Time spent this session 1.5h**

# May 31: Re-did all neopixels and did even more routing

Well, I ended up removing all of the neopixels I had already routed from the schematic and PCB to add reverse mount ones just like I said :pf:

Here's how they look on the schematic now:

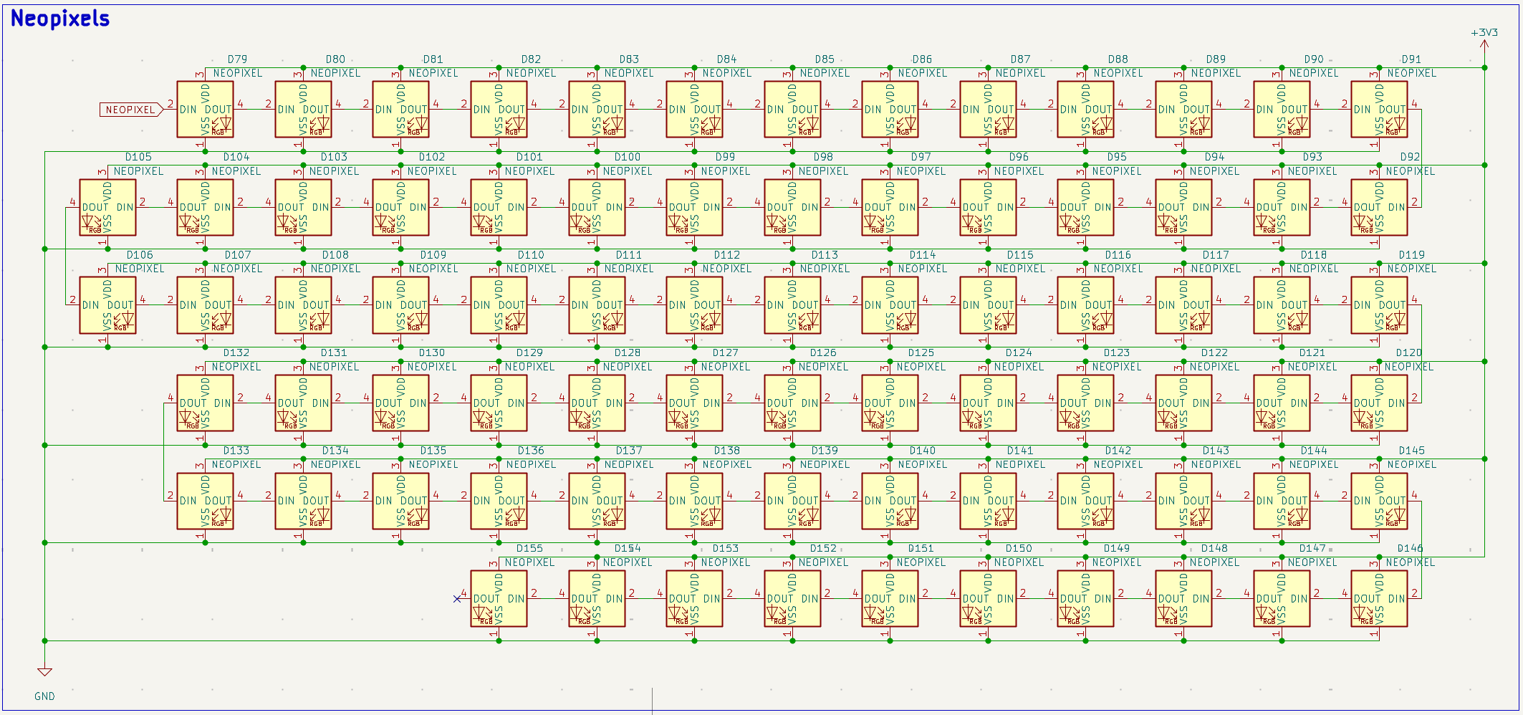
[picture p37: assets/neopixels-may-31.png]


After that, I placed all of them on their respective keys (I actually found out KiCad has an array feature which made this 100x easier!!) and then I routed all of them. It took quite some time because traces I routed before were going over the neopixels' holes and pads, so I had to move around a lot of them to fix the million new DRC errors that popped up 😭

Anyways here's how the PCB looks:

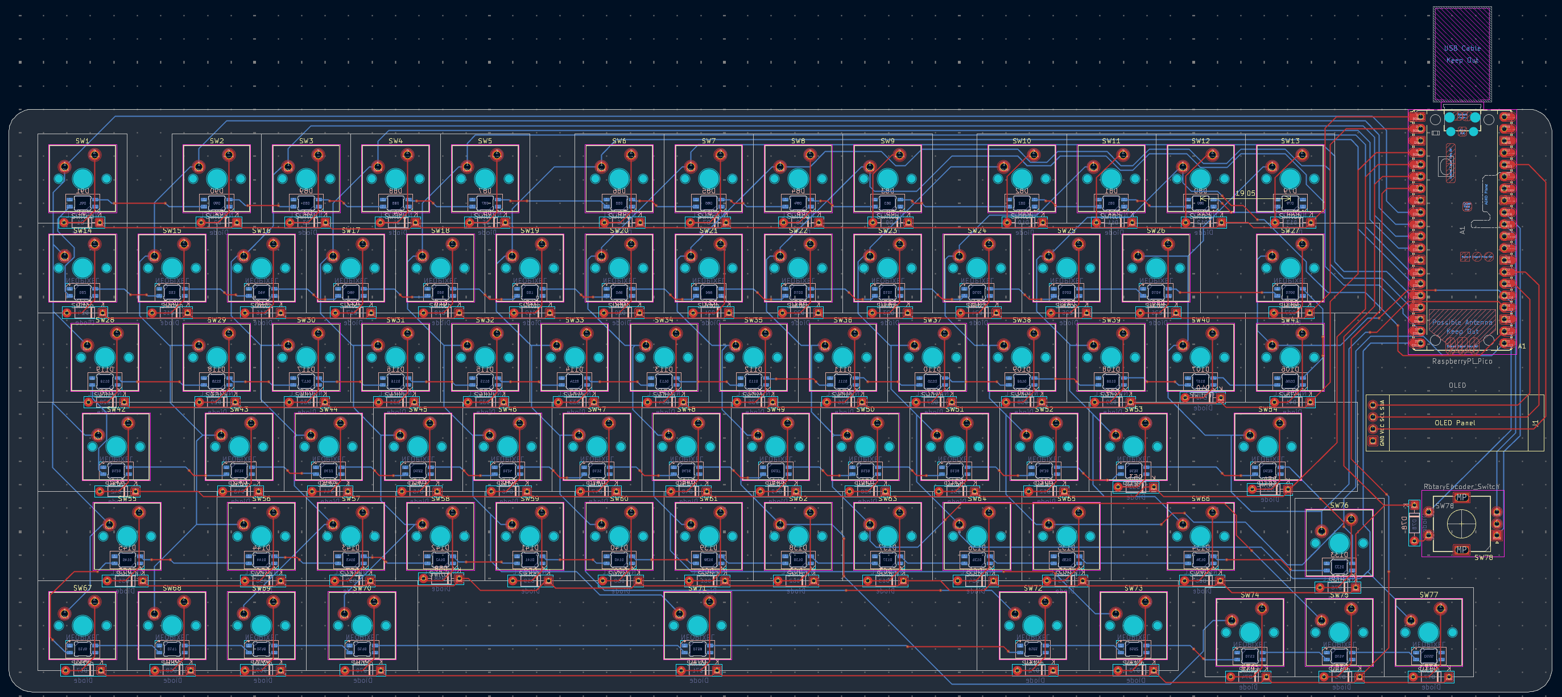
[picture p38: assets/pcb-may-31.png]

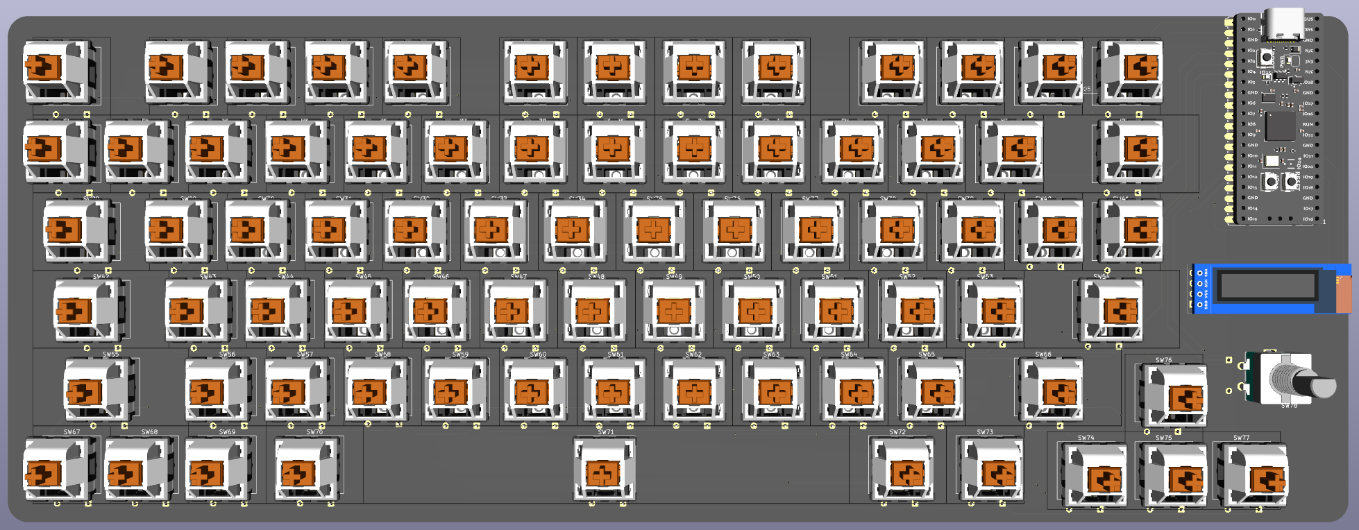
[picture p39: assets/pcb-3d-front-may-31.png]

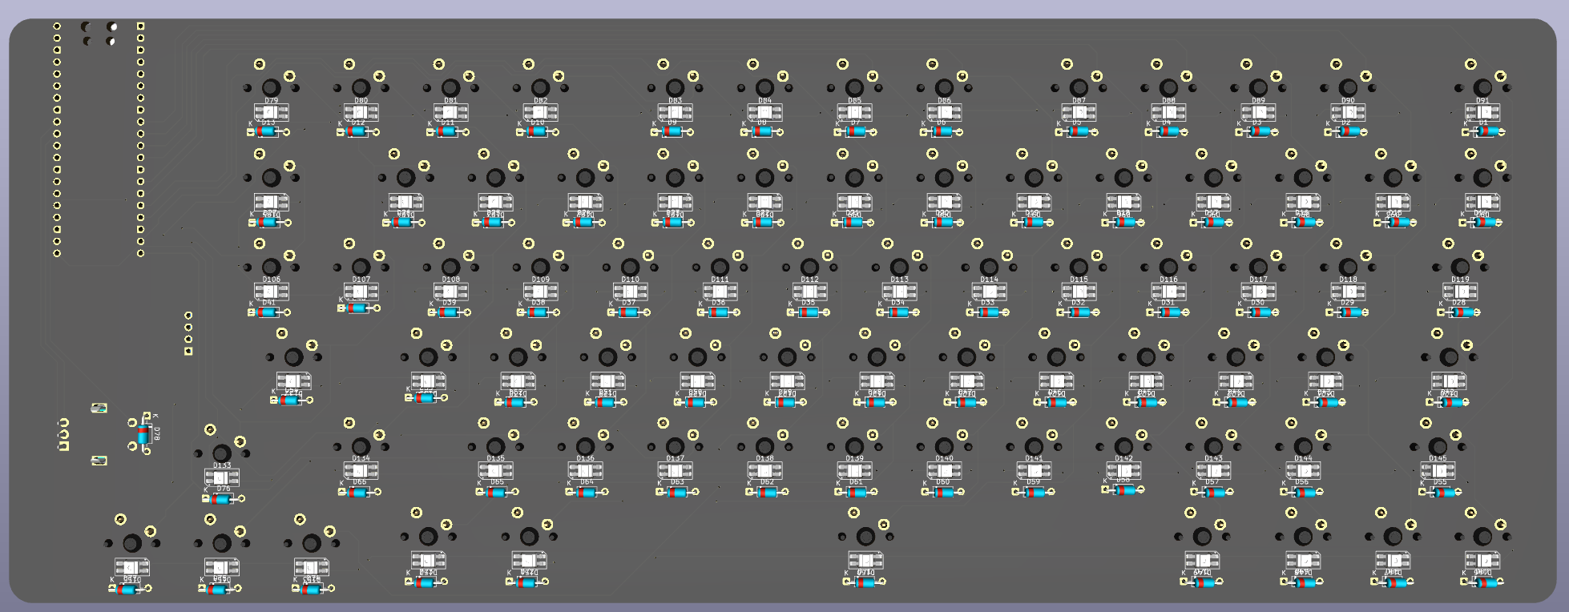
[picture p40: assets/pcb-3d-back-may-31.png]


I still have to route VCC and GND and do silkscreen but I feel like I'm closer to finishing now!!

**Time spent this session: 3h**

# June 1: Finished routing the PCB and (kinda) started with CAD

I'm done with the PCB! (for now at least :pf:)

I noticed for some reason I was missing the stabilizers so I added those again today, and once that was done I added a 3v3 power plane on the front of the board and a GND ground plane on the back. That saved me a lot of time since I didn't have to route GND for all of the neopixels (they're on the back) and I just popped a via in each neopixel VCC pad so that they connect to the power plane on the front.

I still had to spend some time adjusting traces so that all of the planes were connected between each other and everything is routed properly, but I ended up with 0 unconnected items and 0 DRC errors!!

Here's a screenshot of the PCB:

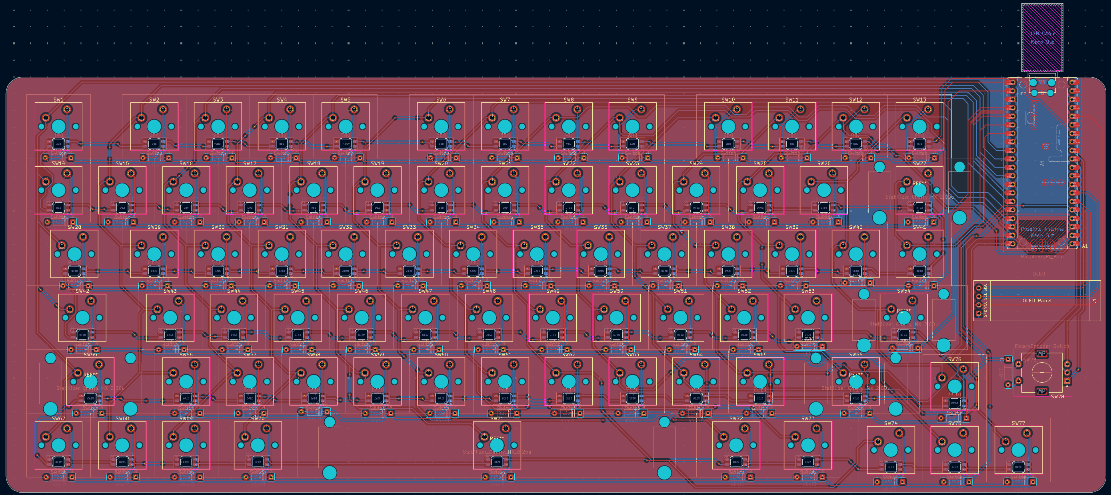
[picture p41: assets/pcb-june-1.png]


And here are both planes highlighted:

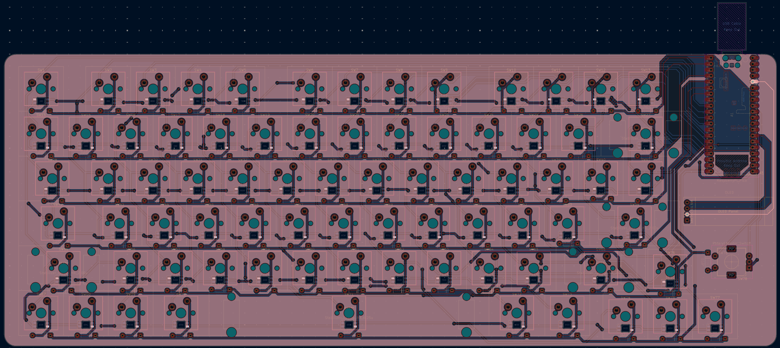
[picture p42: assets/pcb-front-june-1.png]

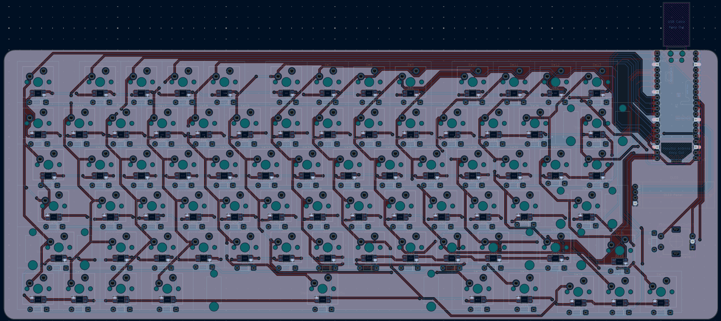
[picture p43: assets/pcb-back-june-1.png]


I do have to adjust the silkscreen and add some art and decorations to it but the technical aspect is done for now. I think it'd be best practice to add capacitors to each neopixel but honestly I do think they'll work fine without and uh I kinda wanna move on from the PCB (at least for now) I'm tired of routing 😭

I also measured the space between keys to design the keyboard plate for the CAD, and got it done pretty accurately:

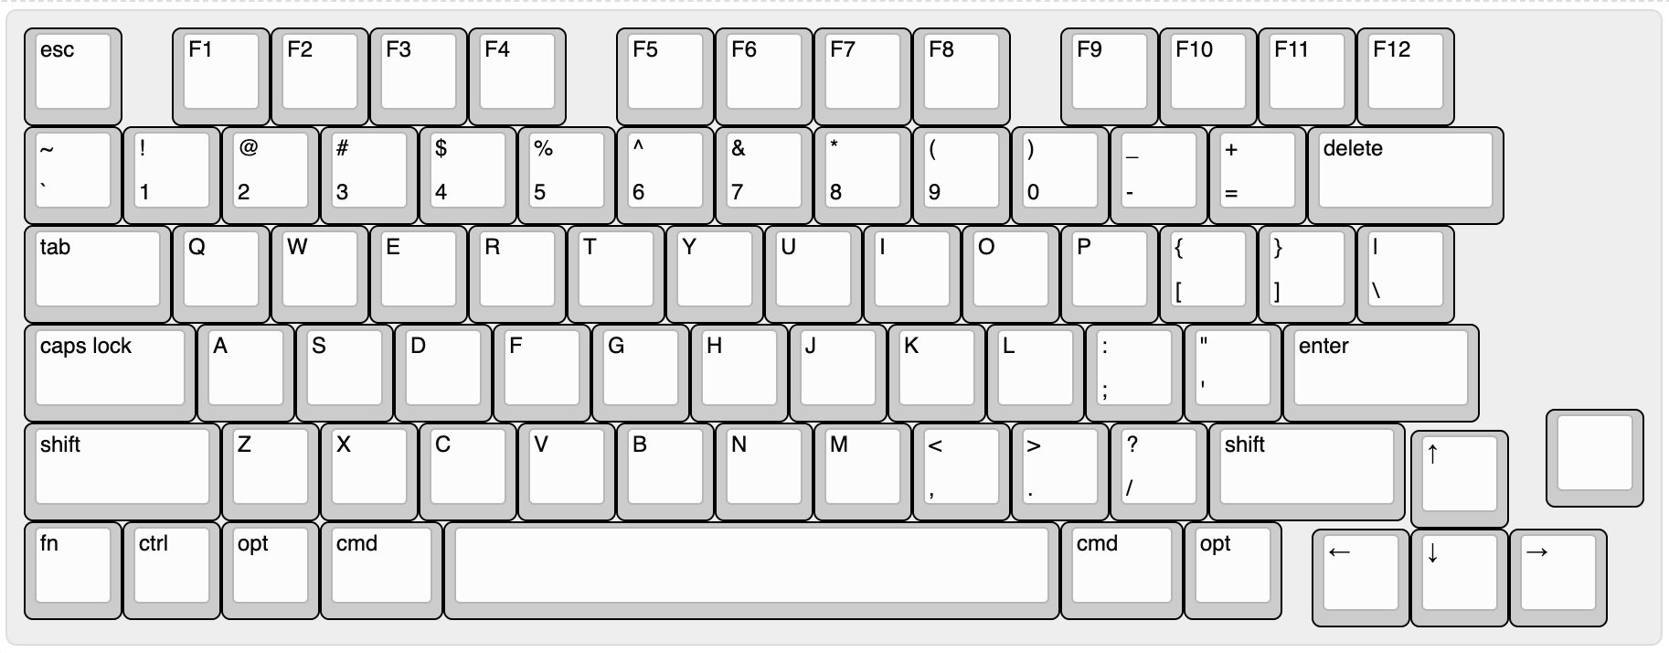
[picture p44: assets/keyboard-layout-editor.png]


After downloading the DXF I played around with it in Fusion for a bit, but didn't really get any work on the case done :pf:

Now I have to think about how I want the case to look and how to like, assemble everything I guess lol

**Time spent this session: 2h**

# June 4: Actually started w the CAD

Today I got started with the CAD in Fusion. I started off looking at alex's orpheuspad's design to see how she put together all of the case's pieces (I'm not ripping off her design, I just wanted to look at the space between parts and how the screws and heatset inserts were positioned and all cause I really suck at that, I'm bad with CAD yall 😭)

Then I started doing a really basic case shape (literally just a gray box w the same dimensions as the PCB) and started placing keycaps above all of the switches. It took me some time because I'm using the exact model for each row :pf:

After that I imported the DXF file for the plate and struggled for some time trying to align it properly. Turns out that for some reason I was trying to make it so it's the exact same size as the PCB and fits inside the case, but idk why I was doing that I'm not mounting the plate like that 💀

Anyways I know it looks pretty ugly right now but I promise this is just a starting point, once I get some time I'll adjust the plate and start designing the actual case. Screenshot:

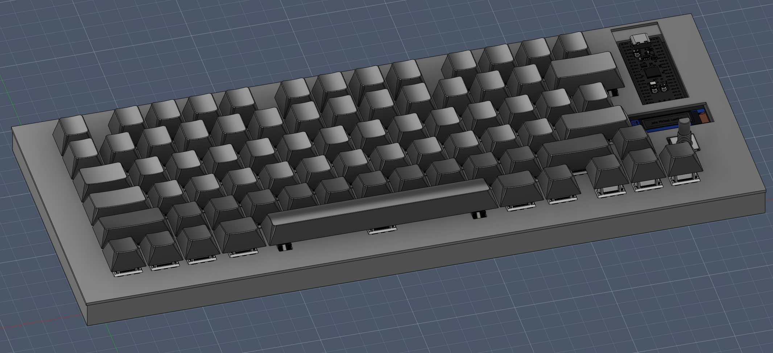
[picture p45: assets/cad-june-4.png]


**Time spent this session: 1.5h**

# June 6: More CAD stuff!!

I did more work on the case today :p

First off, to make it so my plate is aligned with the rest of the case I deleted it altogether and instead inserted the plate's DXF into the original sketch I used to extrude the body. Then I measured the distances between the edge of the PCB and the left-most key in KiCad to calculate how much I'd have to move the plate for it to be aligned with the switches on the PCB. Doing this, I get to use the same sketch for the plate and the body so that they both have the same dimensions.

Then I extruded the plate by 1.5mm just above the body of the case and it was aligned perfectly! :D

After that I started designing the top part of the case, I left some space around the keys so that the keycaps can press down properly and also added holes for the OLED and the pico. I made it 5mm thick, but I might change it later if it's too thin.

Once I had every part extruded I started adding fillets on a lot of places (corners of the case + top part + borders around keycaps, etc) and made the hole for the USB connector look a bit better instead of having it be just a square cutout. I used a chamfer to make the hole for the OLED but I might change it later as I'm not 100% sure it'll look good :pf:

Anyways I yapped too much here are some screenshots :3 (color scheme isn't final!)

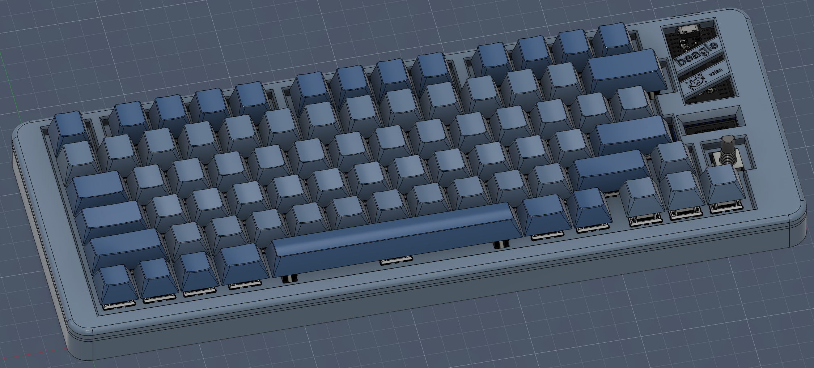
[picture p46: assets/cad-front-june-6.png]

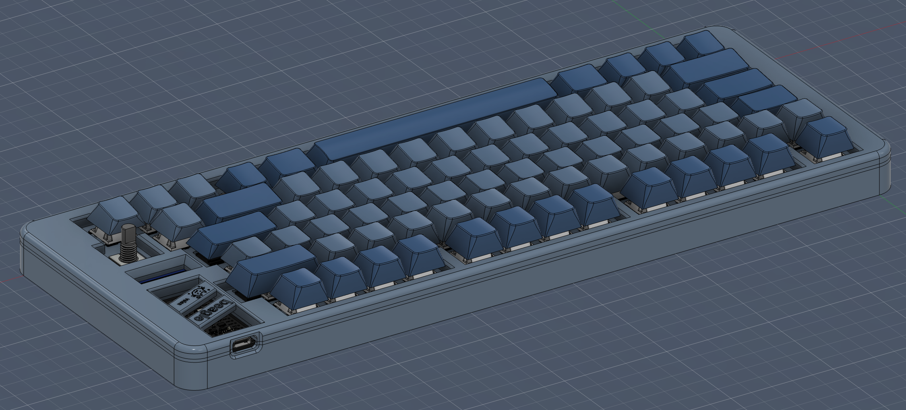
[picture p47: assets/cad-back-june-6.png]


Now I think I only have to add screw holes (and maybe heatset inserts?) and make the base for the case so that it's sitting on an angle if that makes any sense lol

**Total time spent this session: 2h**

# June 11: Figma design!

As the title says, today I did some designing for the PCB's silkscreen in Figma!

First I measured the PCB in KiCad and then I created a frame with a 10px per 1mm ratio so that the design is high quality and proportional to the PCB's dimensions.

Then I just started designing whatever I thought would look cute on the silkscreen, most of it is hand drawn by me except for the stickers and the two little boxes on the left (I think it's pretty obvious my handwriting isn't that perfect lmao)

Screenshots!!

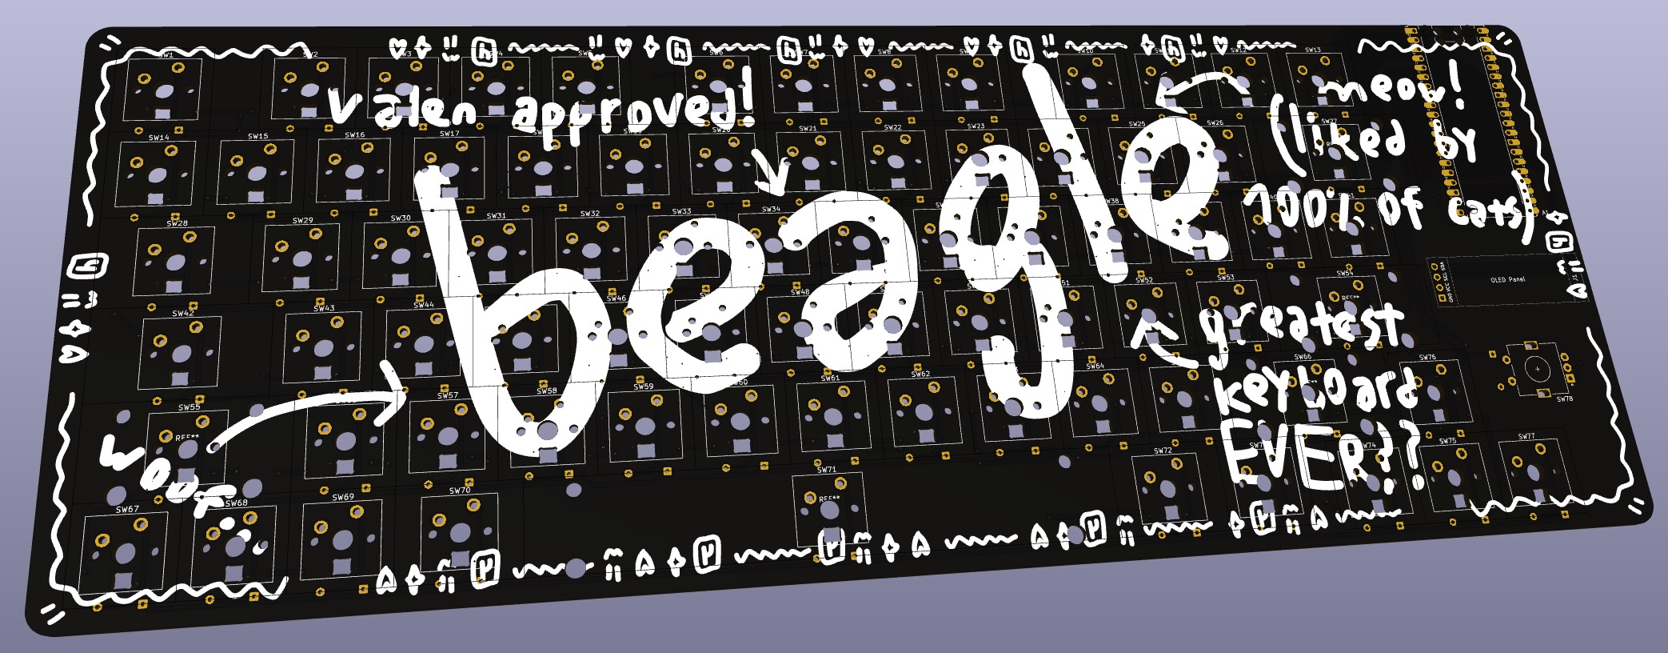
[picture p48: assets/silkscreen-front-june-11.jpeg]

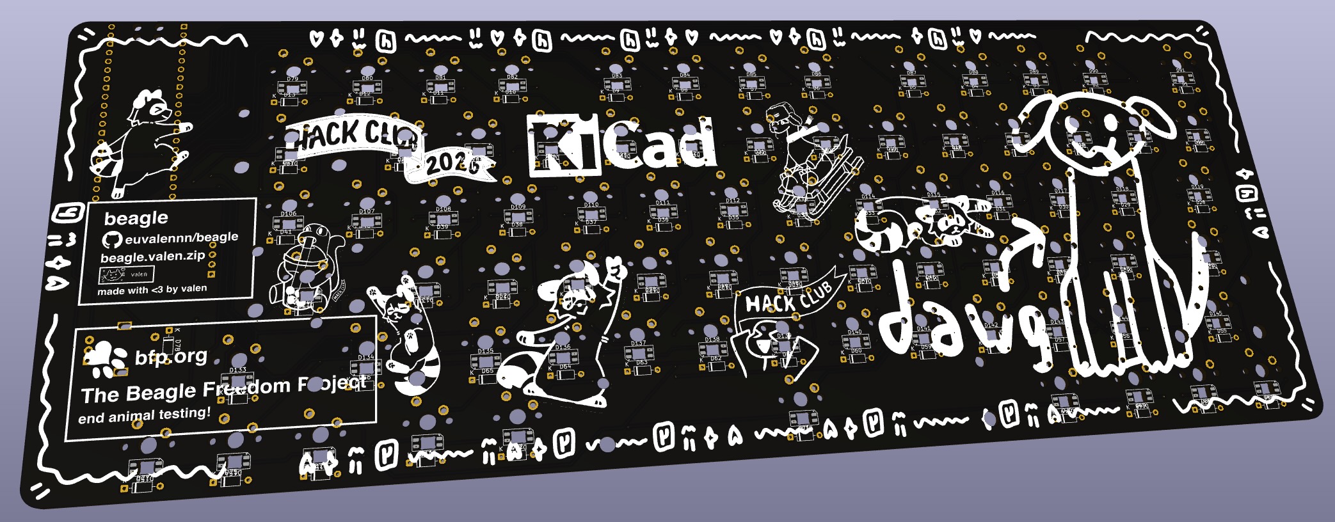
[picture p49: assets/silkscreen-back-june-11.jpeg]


I used Helvetica as the font for the boxes because I wanted to go for an MTA-like design and I think it looks pretty good!

Once all of the components are soldered most of the silkscreen (especially the front side) won't be visible but I still wanted to make it look nice instead of just having a blank black PCB.

Sorry if this entry is a bit short I just don't really know what else to talk about here lol

**Time spent this session: 1.5h**

# June 14: CAD almost done :p

Yet again I've worked on the case today, mostly doing the base.

I wasn't sure how to make it so that it extrudes at an angle (idk if that makes sense lol) but after some googling I realized I could just sketch the base from the side of the case and then extrude it sideways so that it's sitting at an angle and that worked wooooo

After that I started adding screw holes (I think I'm going to use M3 heatset inserts so the hackpad guide was really helpful here) and uhh extruded them onto the case not much to say about that :pf:

Once I was done with that I wanted to add the HC knob model to the CAD assembly but when I was gonna add it I realized I had the wrong model for the rotary encoder (I used the 20mm footprint and the model was definitely smaller) so I downloaded the right model, updated it on KiCad, exported the PCB .step again and then added the new model to Fusion

Then I added the knob model and realized the "h" was sideways (because of the way my rotary was positioned on the PCB) so I struggled for a bit trying to rotate it cause that was easier than changing the footprint on KiCad 😭

Anyway uhh after placing the knob I gave it a nicer color to match the rest of the case and that's it!!

I think I'll try engraving some of the PCB's silkscreen on the back of the case (namely the two boxes and the dog drawing) and probably place 3D models for the screws and inserts to make sure everything fits together

Pics!!

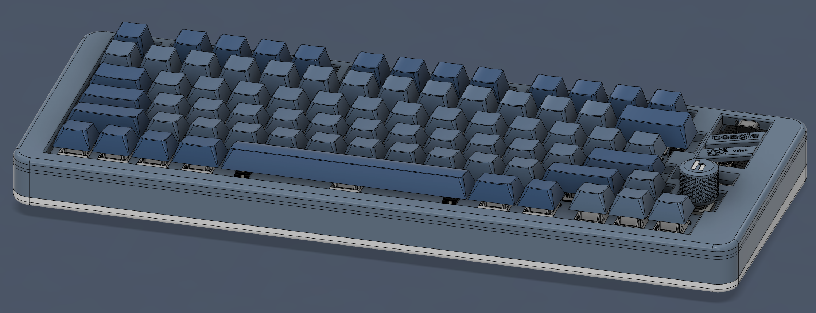
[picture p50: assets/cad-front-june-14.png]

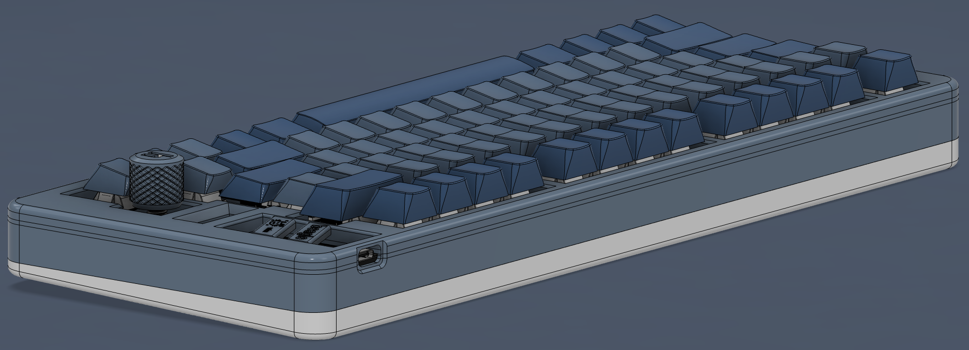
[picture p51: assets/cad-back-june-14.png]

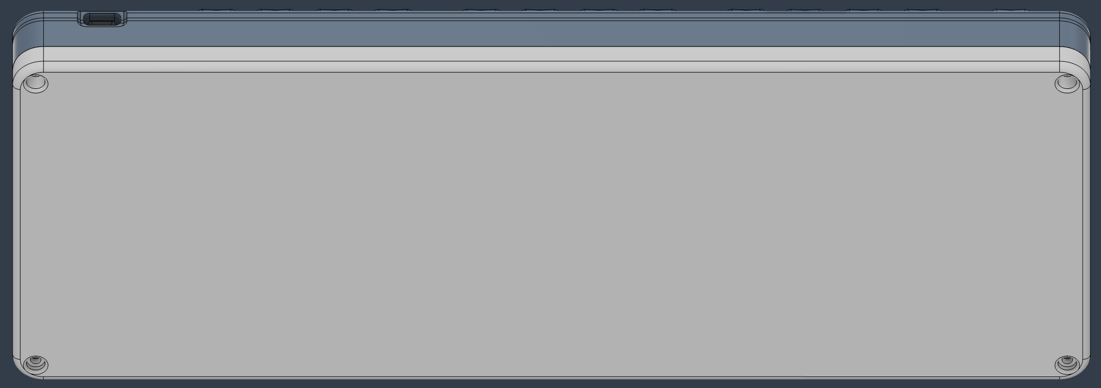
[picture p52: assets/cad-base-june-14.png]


**Time spent this session: 1h**

# June 16: Finished CAD assembly!

First off I changed up my Figma file a bit so that I can export the two info boxes as SVGs and extrude them into the base of the case! I also tried doing the same thing for the dog drawing but it looked weird in Fusion so I didn't include it

Once that was done I looked for 3D models for the inserts and screws to add into the assembly, McMaster-Carr was useful since it had high-quality 3D models of everything

I'm not 100% sure if the engravings I made will look good in the actual 3D print but at least they do in the CAD :pf:

Anyways I don't think I have much more to say so here are some screenshots:

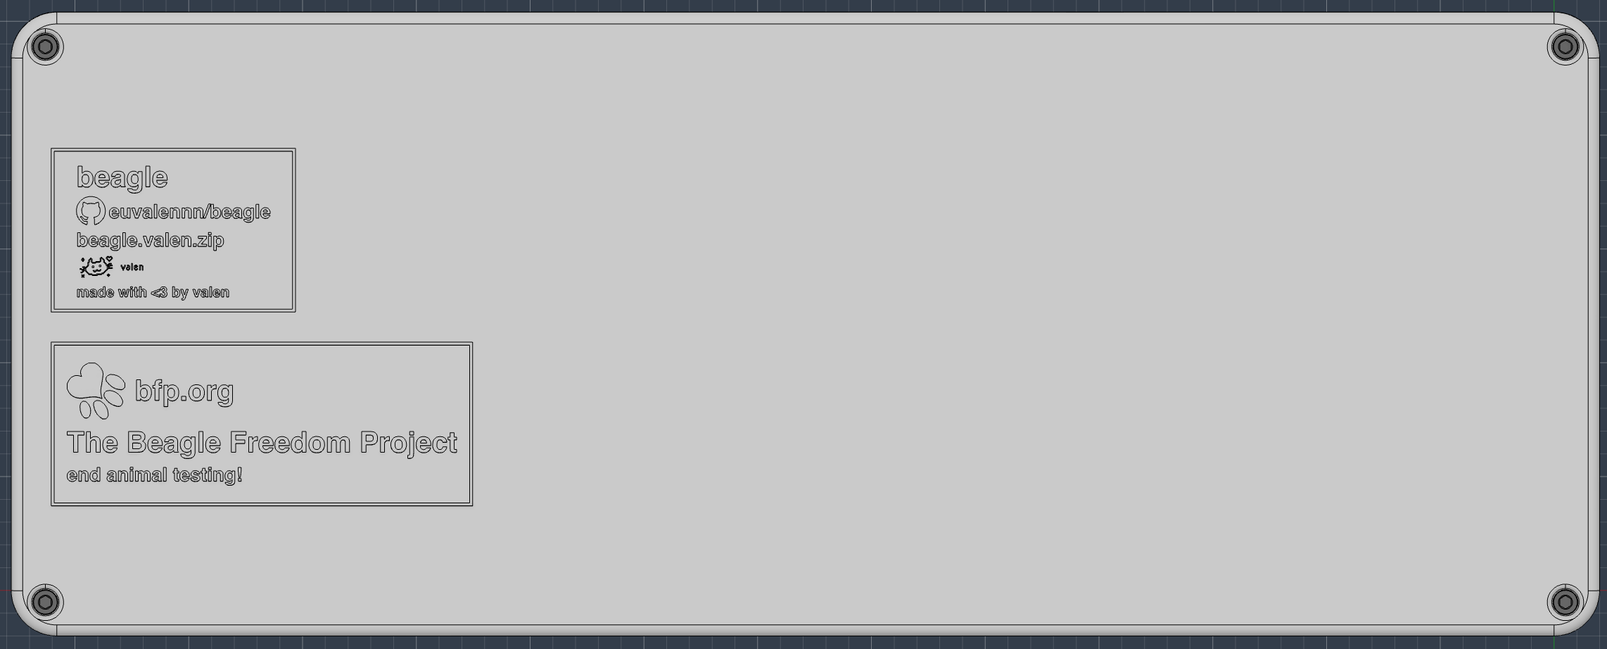
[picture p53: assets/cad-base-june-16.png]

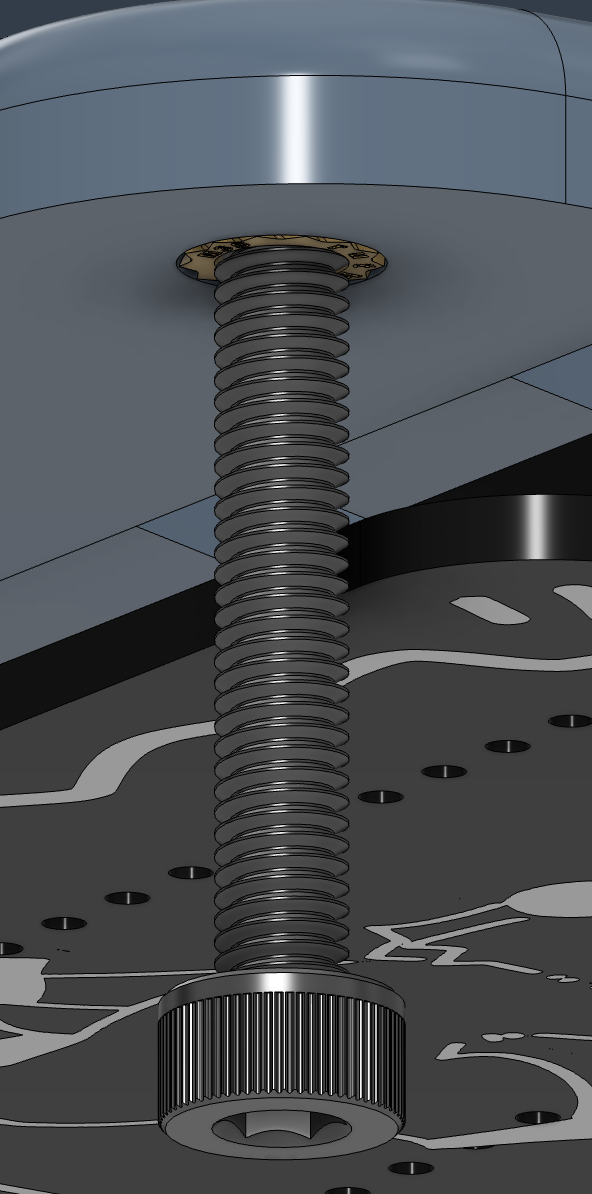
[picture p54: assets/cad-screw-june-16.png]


I think I'm pretty much done now!! I only have to work on the firmware and README now I don't really like doing those but I kinda have to 😭

**Time spent this session: 0.5h**

# August 23: Finally started assembling the keyboard and soldered all neopixels!!

I finally got started building my project IRL!! Yippeeee

First off I soldered the headers on my Orpheus Pico, and honestly setting everything up and getting my desk ready to solder took more time than the actual soldering itself lmao

Anyways I'm still like a total beginner at soldering so I'm pretty happy with how this turned out!!

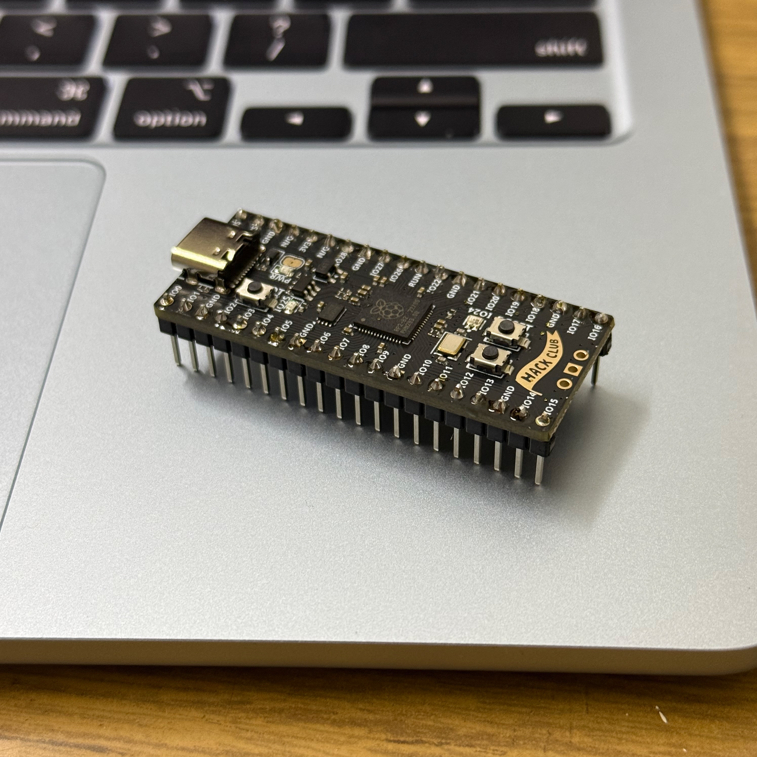
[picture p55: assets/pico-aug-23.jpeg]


Once I got that soldered I went to sleep :pf: (technically this is all one day cause I soldered after midnight lol)

Okay so uhh once I woke up and had lunch I polished the headers' soldering a little bit to make sure they were reliable and then got ready to solder the neopixels even though they're really small and I was terrified of messing up aaaaa

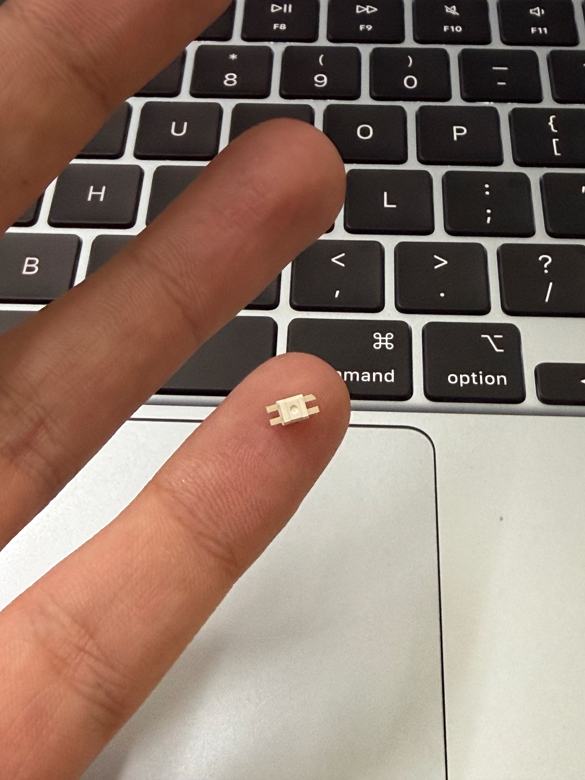
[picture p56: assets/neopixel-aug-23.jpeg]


I got started regardless but the thing is I used some random Chinese flux I bought online because I thought that would supposedly make soldering easier but for some reason it just made everything 10x harder and solder wouldn't stick and um long story short I ended up burning a neopixel's casing just trying to remove it so yeah that sucks 😭

I figured since I already messed up and I have spare PCBs and neopixels I could use this board to practice a little bit so I just tried to solder two more neopixels (one with flux and another one without) and it turns out soldering without any flux is easier lmao I should lowkey return it

This is how the practice PCB ended up looking:

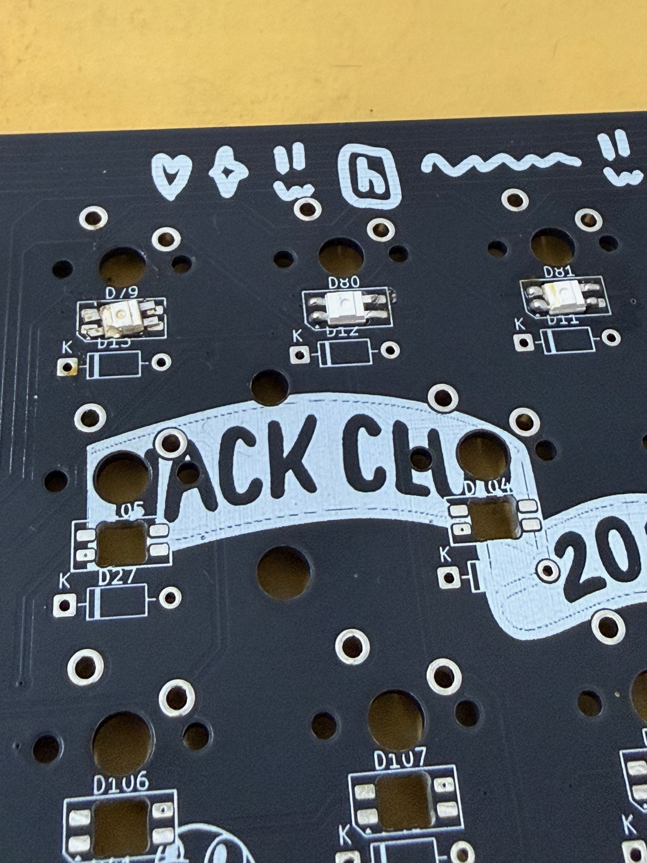
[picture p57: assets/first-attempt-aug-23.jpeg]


I tried powering it on just to see if it would work and surprisingly all 3 neopixels worked??? Nonetheless I didn't want to risk using that board and started from scratch anyways :pf:

Well now that I had some practice I got a new board and started soldering all neopixels with no issues!! I pre-tinned one pad, positioned the neopixel with tweezers and then melted the solder on that pre-tinned pad to lock it into place and be able to solder the rest of the pads. Hopefully that makes sense, here's a pic I took halfway through:



Once I soldered all of them I spent a lot of time trying to figure out a way to test if they worked, I tried connecting the pico pins in the PCB to the devboard with jumper wires but that didn't really work so I ended up just soldering the 3 pins I needed to the board (I'll solder the pico properly later on I just wanted to test the neopixels for now lol)

Even with the pico partially soldered I still couldn't get the neopixels to light up and after a lot of troubleshooting I realized I was missing the libraries I needed for the neopixels to work with CircuitPython 😭

Once I got those libraries and ran the code again only the first neopixel lit up naurrrr

To fix it I just had to touch up some of the pads' soldering and little by little they started working until I got to the last one and got all of them to light up yay

Pic below!!



I also started soldering a few diodes just to see how hard it was and they're actually way easier to solder than the neopixels! Here's a pic of the first 5 diodes I soldered



Anyways hopefully I'll continue soon!!

**Time spent this session: 5h**

# September 1: Finished soldering diodes and pico

I soldered all of the diodes today yayyy

Have some pics :3c




I had to cut the leads but didn't have flush cutters so uh I just used nail clippers instead 💀 (if it works it works am I right)

I also finished properly soldering the pico into the PCB and I think I did a pretty good job! Or at least it looks like it, I just hope it works :pf:

This is how it looks rn



Oh and uh I also noticed one of the neopixels wasn't really working properly and since it broke the chain half of the LEDs didn't light up but I just added some solder to the pads and now it's working again so hopefully it stays like that lmao

Uhhh yeah that's pretty much it!!

**Time spent this session: 2h**

# September 15: Ready to solder switches!!

I finally got my plate 3D printed today!! I had to split it in half for it to fit but I'll figure out how to join it later, I guess it'll be fine since the switches will be soldered onto the PCB anyways :pf:

I also started mounting all the stabilizers but struggled for a bit cause I didn't know how to screw them in but after googling it I managed to do it!! Had to cut some of the diode leads shorter so they'd fit but overall it was pretty easy

Once I was done with that I soldered the OLED and the rotary onto the PCB (it was a little difficult with all the stabilizers getting in the way but I think I did a pretty good job regardless)

Pictures!!



After that I just started (carefully!!) snapping all of the switches into the plate, and by the time I finished it got pretty late so I'll just leave the soldering for another day lol

Pic below :3c



I procrastinated wayyy too much on this but I think I'll finally get to finish it soon :D

**Time spent this session: 1.5h**

# September 19: Finished soldering everything + firmware!!!

I finally got all parts of my keyboard working today!!! Yippeeee

First off I tried to align the plate with the PCB to solder the switches but I did struggle for quite some time considering the plate was split in half and the halves didn't align properly 😭

After a while trying to make it fit I realized I was also missing the switches that went into the keyholes that got split by the seam between the two plate halves (does that make sense?) so to join both halves together I just slid the missing switches on both sides and joined them that way. (sorry I can't think of another way to explain it I just hope that made sense :pf:)

Once I had both halves joined into a single plate, I pushed it on the PCB for a bit until all of the switches were on the same level (it actually took a while lol). Then I just proceeded to solder all of the switch pins which was actually pretty easy and took less time than aligning the plate 💀

After finishing soldering all of the switches I went to take a look at the firmware to finish coding it properly and it actually wasn't too hard for the most part! I think the QMK docs might've changed cause they're more intuitive and easier to understand than I remembered. I set up the rotary encoder for volume and set all of the neopixels to a solid blue-ish color, although they're individually addressable so I might set up some cooler effects when I get more time.

I got really worried when trying to get the OLED working though, cause for some reason no matter what I did it just didn't light up. I genuinely spent like almost 2 hours and didn't go to sleep until 3am just trying to troubleshoot the display 😭

I tried everything I saw online on random Reddit threads and even tested the OLED with MicroPython to see if it was broken but it did work, it just didn't work with QMK.

It turns out the problem was that I set the I2C driver as I2CD1 and looking at the RP2040 datasheet I should've set it to I2CD0 based on the pins I used. Once I changed that the OLED started working perfectly fine and honestly I'm so glad I noticed that because it was such an easy thing to miss :pf:

Well I'm happy to say that the functional part of the keyboard works!! I just gotta get the case and stuff 3D printed now and put all of the keycaps on but other than that I'm pretty much finished yay

Oh and I also made the bottom-left Fn key function as the macOS globe key so that it brings up the emoji picker since I use that a lot! It isn't a built-in keycode in QMK but I found a really convenient guide online (https://skip.house/blog/qmk-globe-key#adding-the-globe-key-to-your-qmk-keymap) that shows how to make it work and it's actually pretty simple! Props to the guy who wrote that guide for making it, his website is really cool haha

Okay I think that's pretty much about it for now :p



**Time spent this session: 3h (maybe like 1 hour soldering and 2 hours on firmware)**

# September 22: Placed all keycaps and tested the keyboard for a bit

I was planning on finishing the keyboard's assembly today but I'm still waiting on one part (the bottom base) to finish printing, so I figured I could at least start placing all of the keycaps!

I am missing one of the right alt/option keys so I just replaced it with an arrow for now lol I might actually just replace some of the 1u keycaps with the ones I got from Outpost though!!

Once I placed all of the keycaps I tried the keyboard for a little bit on monkeytype and while I'm a pretty slow typer the keyboard works well and makes a lot of noise which I like :3

Here's a pic of the keyboard with the keycaps on and some of my monkeytype sessions lmao







**Time spent this session: 0.5h**

# September 23: FINISHED THE KEYBOARD!!!

I FINISHED BUILDING MY KEEB TODAY!! WOOHOO

I finally had all of the parts I needed to assemble everything so today I just inserted the heat set inserts into the top part of the case (it's my first time using inserts but they're actually really easy to use!) and just put everything together to be able to screw it :3

Everything got aligned perfectly and now I'm proud to say I finished my build! Yippeee

I'll leave some pics below and I'll also add some to the README









I'm ready to submit the build now :D

**Time spent this session: 0.5h**

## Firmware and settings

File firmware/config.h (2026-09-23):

#pragma once

#define I2C_DRIVER I2CD0
#define I2C1_SDA_PIN GP20
#define I2C1_SCL_PIN GP21

#define WS2812_DI_PIN GP28
#define RGBLIGHT_LED_COUNT 77
#define RGBLIGHT_LIMIT_VAL 128
#define RGBLIGHT_DEFAULT_HUE 148

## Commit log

2026-06-26 added readme, bom, and all project files
    [0.91in OLED Module - Without Glass.stp, 100mill Male Pin Header_10P_Bk.STEP, 100mill Male Pin Header_10P_R.STEP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]
2026-07-02 updated bom
2026-07-02 updated bom.md
